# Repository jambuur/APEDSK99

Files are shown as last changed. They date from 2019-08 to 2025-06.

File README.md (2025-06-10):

# APEDSK99 (Arduino Peripheral Expansion for the TI-99/4a)

### *July 2025 Newsflash: WiFi suggestion*
I did get a number of questions regarding a WiFi option using the Arduino WiFi shield. Initial investigation suggested a lack of memory so to make it fit I had to reduce other functionality. This I didn't want to do. However, there is a simple solution. There are devices that accept a wired Ethernet connection and bridges this to a WiFi network of your choice. It works a treat. Check out IOGEAR etc.

### *July 2024 Newsflash: IDEDSR adaption*
I am currently trying to adapt Fred Kaal's version of the DSR for Thierry Nouspikel's IDE card to APEDSK99. Not sure of a successful outcome yet as there are major design and hardware differences to take into account; the first experiments are encouraging though. If it works it will be a valuable addition to APEDSK99 as you would be able to mount and use existing MAME HD images on your TI. It will also save me from the big headache of trying to define APEDSK99 as a new device in MDOS (see below).

### *January 2024 Newsflash: Case 3D design files available*
With the help of an Industrial Design student I have finalised a case for APEDSK99, (loosely) following the style of the Speech Synthesizer. 
On a side note, I have been able to lay my hands on a Myarc Geneve card. As I don't have a PE Box I am building a standalone system including a modified APEDSK99 for booting and floppy / HD emulation. 

### *February 2023 Newsflash: Major Update in progress*

Check the TI Italian User Club for a review of the new version: https://www.ti99iuc.it/web/index.php?pagina=articoli&artid=219#.Y-gqDi9BxaS

Currently working on updating this Github page, Youtube channel etc. Biggest takeaway is that APEDSK99 is now pretty much plug and play. 
I am thinking of either supplying pre-assembled APEDSK99 shields, leaving it to you to source a cheap Arduino UNO + Ethernet Shield combo from Ebay, AliExpress etc.
Alternatively, I could supply complete kits; I have also been approached by a web shop interested in the same. 
Stay tuned :-) 

### *Arduino-based DSKx emulator / 32K / FTP / NTP shield for the TI99/4a*

APEDSK99 is an Arduino shield that emulates 3 DS/SD/80T floppy drives for the TI99/4a home computer. Combined with a Arduino UNO and an Ethernet / SD shield it allows you to load, save and use disk floppy images (DOAD) on a SD card or FTP server. It includes the necessary 32K RAM expansion and adds NTP date and time to BASIC. The APEDSK99 shield plugs directly into the side port and is powered separately from a USB cable. 

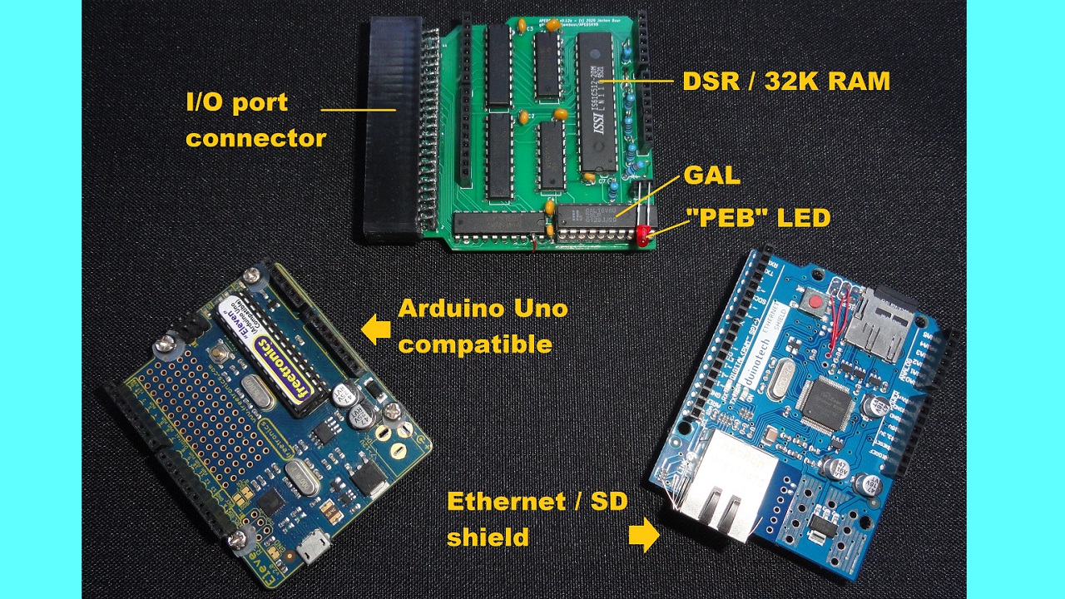
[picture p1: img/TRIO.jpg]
KiCAD 3D view


Like the TI, APEDSK99 is based on good old through-hole technology. The TI<->shield interface is the familiar design, with 74HCT541 buffers for address lines and a bi-directional 74LS245 buffer for the databus.  A 64Kx8 RAM stores the DSR code and provides the 32K RAM expansion. CRU is emulated through memory mapped addresses, simplifying shield design. A user-selectable binary DSR file is loaded into RAM at >4000 by the Arduino at powerup / reset. 

The Arduino UNO controls the TI interface, has R/W access to RAM, can halt the TI and tries to act as a FD1771. As GPIO pins are in rather short supply, Arduino RAM addressing is serial-to-parallel through 74HC595 shift registers. 

A status LED indicates APEDSK99 access as well as showing possible error codes.

The DSR is still very much the original TI Disk Controller ROM, but adapted to interface with a reliable SD card instead of wonky floppies. 
DSR code optimisation made enough RAM available to include some useful BASIC CALL routines. I think it's rather nice that most of the orginal programmers' blood, sweat and tears lives on.

### *How does it work?*

When the TI issues disk controller commands by writing to the various FD1771 registers, the Arduino receives an interrupt on one of its GPO pins. This interrupt is generated by a GAL which monitors A0, A13, A14, A15, WE* and MEMEN* sideport signals. On receiving an interrupt, the Arduino then:

1. halts the TI by making READY low; this simultaneously enables the shift registers
2. disables the sideport interface buffers
3. enables the Arduino RAM control bus
4. executes the command including updating the relevant FD1771 and CRU "registers"
5. executes the opposite of steps 3, 2 and 1

The GAL also does the memory decoding for the 32K memory expansion.

### *DOAD's*

DOAD's are stored in root folders on the SD card or on a FTP server. Default APEDSK99 files include a DISKS folder with a bunch of useful images to get you started. DOAD filenames must follow the DOS 8.3 format and have a ".DSK" extension. At powerup or reset the Arduino looks for optional \_APEDSK1.DSK / \_APEDSK2.DSK / \_APEDSK3.DSK_ files and maps them accordingly so you can have your favourite apps ready to go. The DSR includes all necessary CALL's for DOAD and DSK management.

Once a DOAD is mapped to a particular DSK, it behaves very much like a normal (but rather speedy) floppy. 

Regarding FTP, on my setup (a Linux server with VSFTP within the same LAN segment) I get about ~22Kbyte upload / download speed. In practice it means 6-7 seconds between the TI-BASIC FTP CALL for a SS/SD image and back to the friendly flashing cursor.

### *BASIC support*

The DSR includes some 15 additional BASIC CALL's but there is really only one to remember, **CALL AHLP**:
<p align="center">
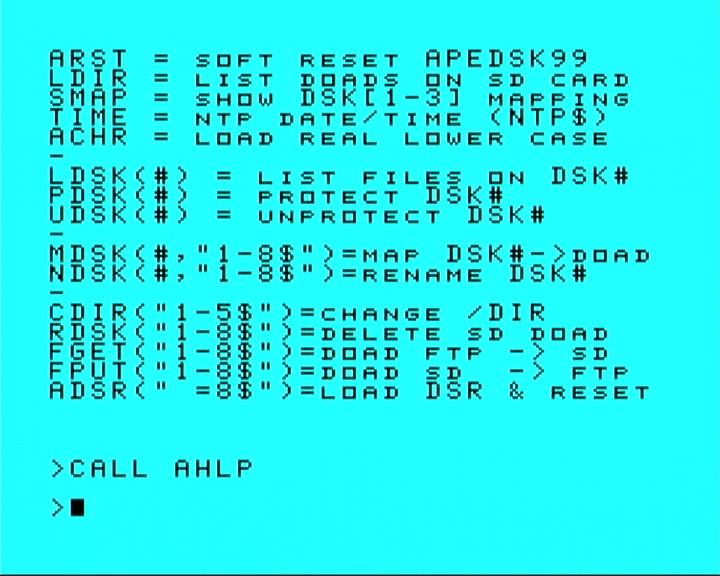
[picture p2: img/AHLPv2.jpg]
  
</p>

**CALL ARST** resets APEDSK99 including reloading the current DSR. It is a handy way to get your DOAD mappings to their default state. It is functionally the same as pressing the Arduino reset button and sort of the same but not really as power cycling. 

**CALL LDIR** list the DOAD's in the current selected directory on the SD card, displaying the DOAD name, TI DISK name and DSK characteristics:
<p align="center">
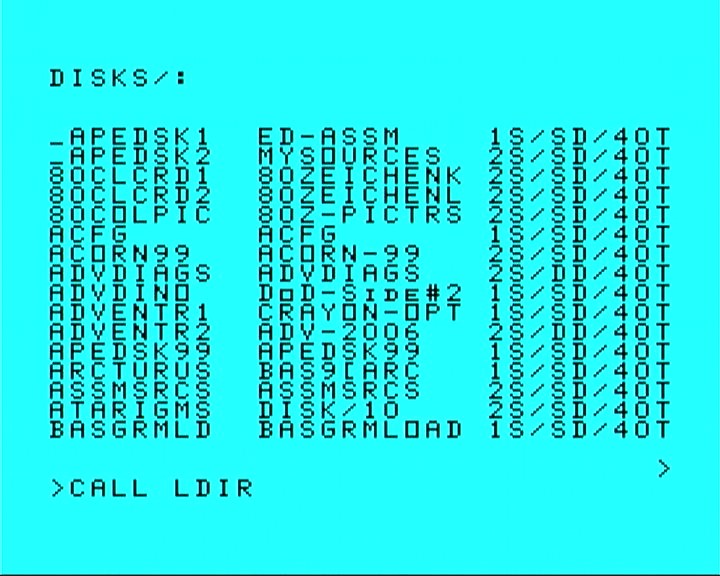
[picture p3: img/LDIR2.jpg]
  
</p>

**CALL SMAP** shows the current DSKx -> DOAD mappings, extended info and the available directories on the SD Card:
<p align="center">
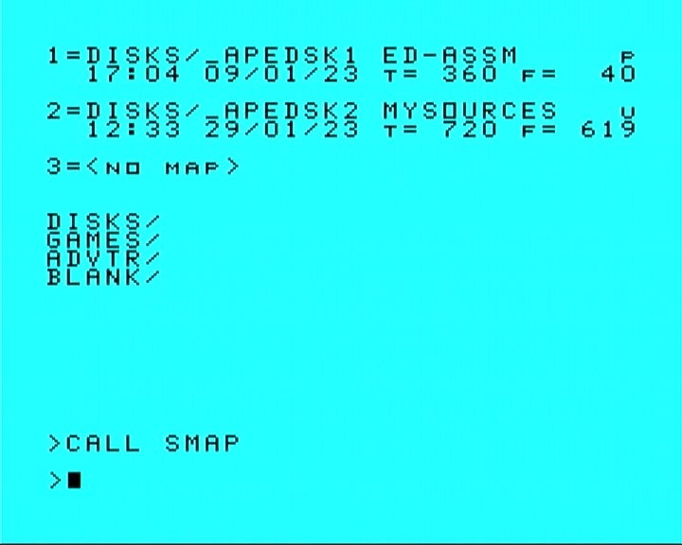
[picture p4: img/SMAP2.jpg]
  
</p>

**CALL TIME** gets the current date and time from an NTP server. If you define a BASIC variable NTP$ of exactly 16 characters before the CALL, the NTP data will be stored for use in your programs:
<p align="center">
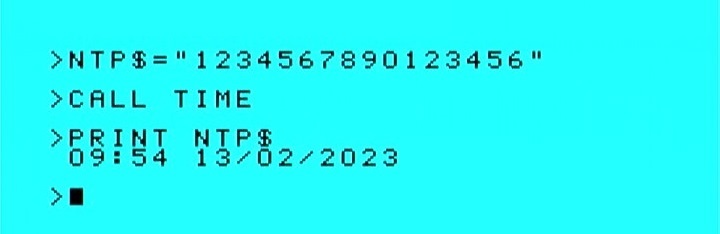
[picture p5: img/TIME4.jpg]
  
</p>
NTP is also used in the background to update a DSK's timestamp when creating/changing files or formatting.
<br/>
<br/>

**CALL ACHR** redefines the "lower capital" character definitions to true lower case. It's a bit of a bummer that BASIC constantly reloads the original definitions in command mode so you can really only enjoy lower case characters while running a BASIC program. What has this feature  to do with DSK's I hear you ask? Well, nothing really but it gives you an example of developing useful CALL's with APEDSK99: 
<p align="center">
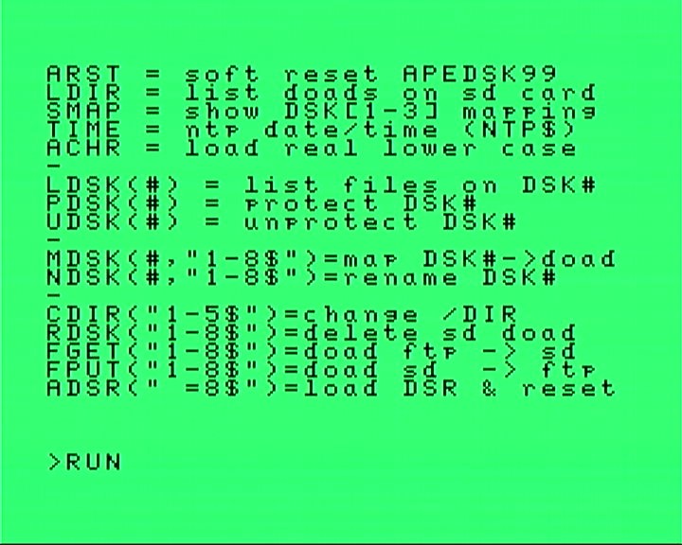
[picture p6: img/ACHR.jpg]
  
</p>

**CALL LDSK** list the files on a DSK; I always thought that was a really nice feature of the C64 so here it is. LDSK uses the last DSK\# that was accessed if you ommit the [1-3] parameter:
<p align="center">
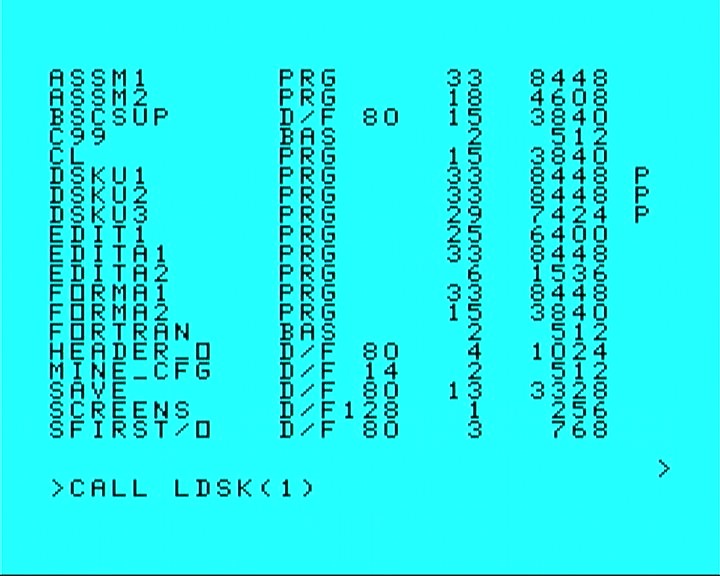
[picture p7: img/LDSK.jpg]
  
</p>

**CALL PDSK** and **CALL UDSK** apply or remove a virtual "sticker tab" (remember those?). With the "tab" applied, APEDSK99 can't write to the DSK. Under the hood the Protected flag at 0x10 in the Volume Information Block is set/reset:
<p align="center">
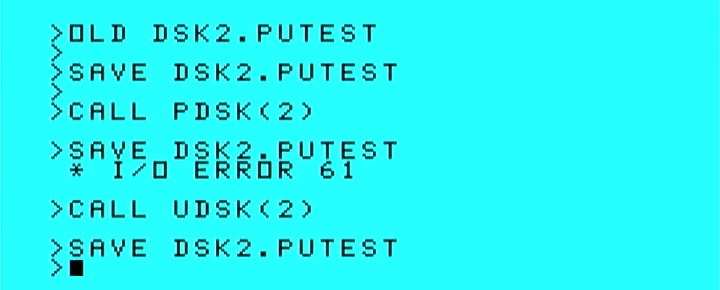
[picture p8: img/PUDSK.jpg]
  
</p>

**CALL MDSK** maps DSK[1-3] to a DOAD. The DOAD file name is the DOS max 8 character part without the extension (see **CALL LDIR** above).  

**CALL NDSK** renames a mapped DOAD. The TI DISK name is set to match the DOAD 8 character name. With renaming the DSK, the current mapping is deleted as the DOAD has now a new name. This command is handy for quickly creating a freshly formatted DSK. Just **FGET** a clean image (I use either FLOPPYSS.DSK or FLOPPYDS.DSK) and rename accordingly.

**CALL CDIR** changes the working directory. The SD Card image contains a /DISKS folder with lots of goodies and a /BLANK directory with the abovementioned clean images. One restriction is that you have to create additional directories on an external system as there is no CALL for that. 

**CALL RDSK** removes a DOAD from the SD card. In line with BOFH standards no confirmation is required but the DSK in question needs to be UNprotected.

**CALL FGET** and **CALL FPUT** load or save a DOAD from your FTP server of choice. Similar to **RDSK**, to overwrite an existing DSK on the SD card it needs to be UNprotected. To prevent overwriting images on your FTP server simply make them read-only.

**CALL ADSR** loads a DSR file from the SD card and resets APEDSK99. If the DSR file doens't exist or is invalid the default file APEDSK99.DSR will be loaded instead. The current DSR filename is stored in EEPROM so will survive resets and powerdowns. After loading a DSR, a soft-reset may be required to execute any DSR powerup routines. 

NB: 
**LDIR** and **LDSK** can generate multiple screens of info. A ">" will show up at the bottom right for you to press either \<SPACE\> for the next screen or \<ENTER\> to go back to the BASIC prompt.

### *APEDSK99 configuration*
Configuring APEDSK99 is easy. All it takes is to run a BASIC program called ACFG from DSK1:
<p align="center">
  
</p>

The program has to run from TI BASIC (why? see _What about Extended BASIC_ below):
<p align="center">
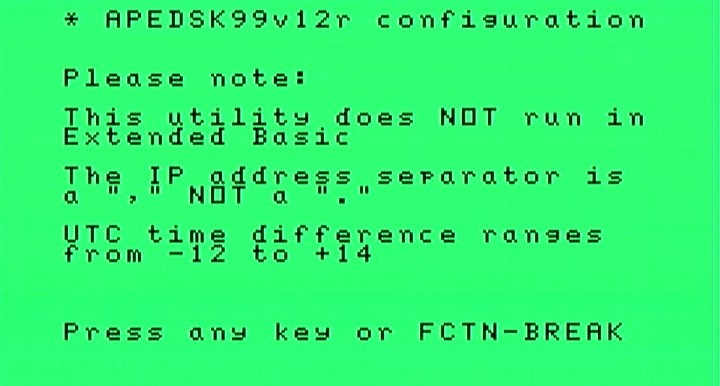
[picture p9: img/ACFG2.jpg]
  
</p>
  
The programs shows the current configuration before asking for updates. 

The new configuration is then applied to APEDSK99. If NTP is successfully configured the program shows the local date and time. The configuration is saved in EEPROM and used with every reset / powerup:
<p align="center">
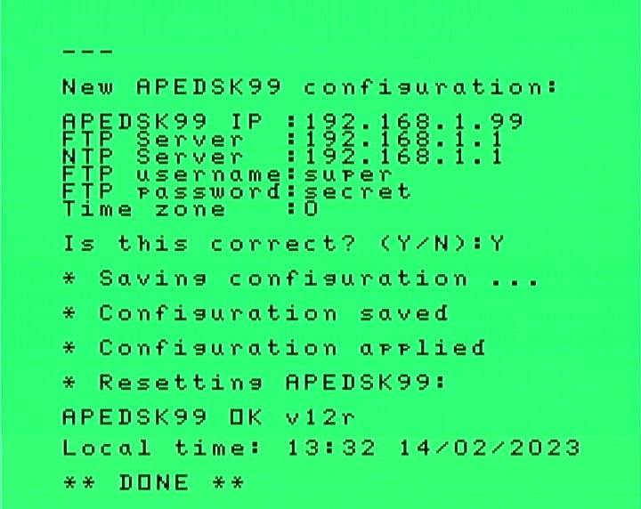
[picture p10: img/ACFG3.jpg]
  
</p>

### *What about Extended BASIC*
Yes, good question as I take it EXBAS is used over TI BASIC by the majority TI enthusiasts. Obviously I wanted to support vanilla console users (like the ones re-entering the hobby after xx years such as myself). But that doesn't explain why EXBAS couldn't be used to run the configuration program. Well, the problem is that EXBAS doesn't support external CALL's in programs, only from the command line. This would mean you have to type in a set of commands instead of a more or less automated setup. Not a good idea I thought.

**UPDATE 16/1/2024**: I now have provided EXBAS support through CALL LINK as an alternative to execute DSR CALL code, for example CALL LINK("MDSK",1,"ACFG"). Adapting the configuration program to EXBAS is left as an exercise to the reader.

### *Ignition sequence*

The DSR containes a powerup routine (the original TI DISK Controller routine if fact) that needs to be executed before you can properly use DSK's.
So switch on the TI first, apply power to APEDSK99, wait a second for APEDSK99 to load the DSR (short flash from the LED) and then soft-reset the TI with \<FCTN\>-\>QUIT\> to execute the DSR powerup routine.

### *Error codes*

The LED can flash in the following intricate error patterns:

1. *flash*            : SPI / SD Card fault/not ready
2. *flash-flash*      : can't read DSR binary image (/xxxxxxxx.DSR)
3. *flash-flash-flash*: no valid DSR header (>AA) at DSR RAM >4000

### *Uploading Sketches*

You should make sure APEDSK99 is idle or even better, switch off the TI before uploading the APEDSK99 sketch from the Arduino IDE. If you don't, there is a slight chance the Arduino bootloader gets corrupted and you'll need a second Arduino to restore it. Yes I have been there.  

Alternatively you could connect [_Analog 1_ to _+5V_](img/A15V.jpg) with a jumper wire before uploading; this disables the APEDSK99 sideport buffer IC's so you can leave the TI powered on. In fact, if you intend to put APEDSK99 in some sort of case, plan a switch for this. It's not only handy for uploading sketches but also for temporarily circumventing _TI Extended BASIC_'s LOAD feature.

### *Updating the DSR*

I compile the DSR .a99 file with [xtd99 TI99 cross development tools](https://endlos99.github.io/xdt99/) and then use [this hex editor](https://mh-nexus.de/en/hxd/) for padding the binary file with zero's to the full 8KB. After that it's just a matter of saving the binary file as APEDSK99.DSR in the root of the SD.

### Feeling Brave - DIY from scratch

If you decide to build one yourself, I have compiled a handy document to get you started. Just ping me with any questions through Github, YouTube or AtariAge (JJB).

### A suitable case

I have teamed up with an Industrial Design student from a local university and have come up with the design below. It (very) roughly follows the design of the Speech Synthesizer and has a handy hatch to access the SD card and reset button:

<p align="center">
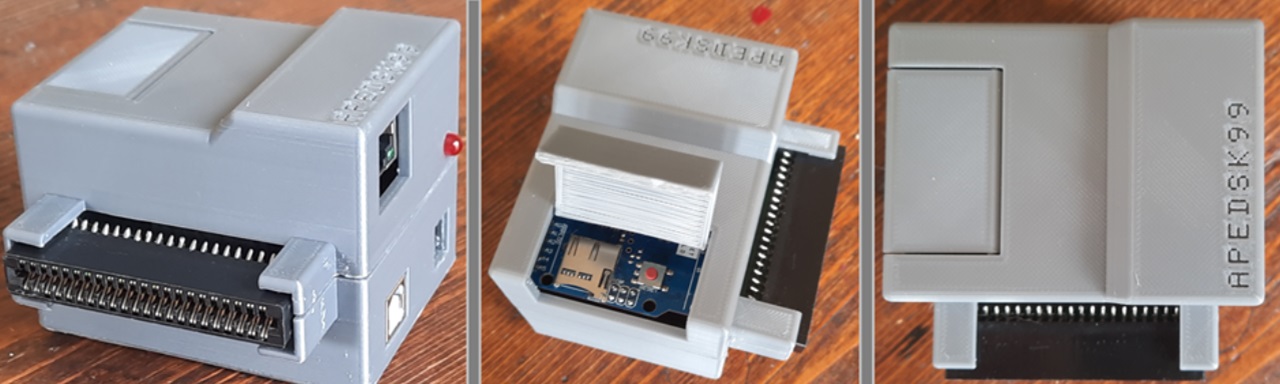
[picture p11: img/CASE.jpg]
  
</p>

### *I know*

Writing software is a hobby, not my profession. No doubt some gurus would achieve the same functionality with half the code. But I dare to say that at least the basic DSR I/O routines in the sketch are reasonably efficient, useful and fast. Anyway I am content with dusting off that stack of virtual floppies, have a beer and admire my work. 

Feel free to improve and share!

### *Bugs*

If a particular program or module behaves nicely by accessing disks solely through the regular DSR routines there shouldn't be any new ones (are there any existing disk controller bugs?) In other words, any funky index hole math or weird copy protection schemes will likely fail. 

Not so much a bug but an annoyance is that the FAT format (as used on the SD Card) doesn't support any sorting whatsover; so if you have been actively **FGET**'ing images from your FTP server you might find the **SDIR** list slightly out of alphabetical order. There are a number of "FAT Sorter" programs for different OS's that can restore the order for you (the one I use is included in the repository).

And yes, if I had thought it through a bit more I would have designed APEDSK99 with the USB and Ethernet connectors facing backwards. Anyway what's done is done and unless there is a push for a major revision (unlikely) you'll (we) have to live with this minor inconvenience.

### *Future*

After (of course) I came up with the name APEDSK99 I realised that DSK emulation is just a first application. The APEDSK99 shield is actually a generic interrupt-driven DSR interface to a substantial catalogue of available Arduino shields. Also, the Arduino has full access to the 32K RAM expansion and since it uses a 64Kx8 RAM chip there is an additional 24K available for additional DSR, program code or device data sharing.

### *Acknowledgements*

This project owes a lot to Thierry Nouspikel's marvelous [TI Tech Pages website](http://www.unige.ch/medecine/nouspikel/ti99/disks.htm) which has a wealth of information on the TI Disk Controller, including a commented disassembly of its DSR ROM.

Another great source of information has been Monty Schmidt's excellent book [Technical Drive](img/MSTDrive.jpg). Monty went on to do great things, check out [SoundForge](https://www.magix.com/us/music/sound-forge/). Monty has now made his book publically availabe: https://github.com/wuntusk/technical-drive

The Arduino's serial-to-parallel RAM addressing scheme is neither new or mine but I have gratefully used part of [this excellent project](https://github.com/mkeller0815/MEEPROMMER) by Mario Keller.

Last but not least I virtually stumbled across my old friend Frederik "Fred" Kaal who I hadn't seen for 30 years after moving to the other side of the globe. Long live the Web and places such as AtariAge. Fred was a TI wizzard back then and [still very much is](http://ti99-geek.nl). His expert input has been of great help.

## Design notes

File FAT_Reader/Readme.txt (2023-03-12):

---------------------------------------------------------------------------
  FAT Reader v0.8 rev.1                             written by: A. Sanasi
---------------------------------------------------------------------------

Introduction
------------

Ever since MS-DOS based Windows98 was discontinued, I longed for a way
to physically sort directory entries to my liking (I still make extensive
use of the Command Prompt and hate it when things are not orderd as I
want).  Before that I had used the fabulous LFNSORT command-line tool by
D.J. Murdoch, which alas does not work on NT-based operating systems.

Even after many years, still no program seems to be able to do this job
right.  Some programs only check drives connected to the USB port, allow
only alphabetical sorting with no manual sort options, sort only music
files, or even require Windows Media Player to be present.  But what if
you want to sort other things too?  Like image files on a digital frame
or video files on your local harddisk?  Or if you simply prefer a
non-alphabetical order with directories and files in a special
arrangement?

Other programs just work with tricks by simply moving all files into a
temporary directory and then move them back in the desired order.  The
problem with this approach is, when you have for example 50 file entries
that you move out of a directory and then back, you don't get 50 sorted
file entries, you get 50 (invisible) deleted entries followed by 50 normal
file entries, because Windows will always try to append first when creating
new entries, not overwrite.  Even worse, when the cluster of a directory
can hold let's say 128 entries and you move 100 files out and back in,
Windows will first use up the remaining 28 free entries and then start
overwriting the entries marked as deleted (because that's more efficient
than allocating a new cluster to expand the directory), resulting in file
entries 29 - 100 being on top, followed by 28 remaining deleted entries,
followed by file entries 1 - 28.

The only program and my personal favorite that really gave you full sorting
control was YAFS (Yet Another FAT Sorter) by Luis Henrique Oliveira Rios.
Alas, this one has no GUI and works with .XML lists that you can only
handle with an appropriate editor, and you have to set the new order by
manually changing numbers individually for each file, which is VERY
tedious.  It also seems to not keep deleted entries, so you can't undelete
anything after the sorting anymore in case you need to.

Luckily, recently a friend explained the basics of VB .NET to me through
Skype (all I knew before was a little bit of x86 assembler), and with that
knowledge I was finally able to write my own program.  Aaand here it is! ;)
This one not only has a GUI, but can also do real sorting on the filesystem
level.  And since it communicates with the device drivers, it should be
able to handle all drives that Windows recognizes as FAT, be it MP3 player,
USB stick or harddisk, even mounted TrueCrypt volumes work.

Disclaimer
----------

This really is my VERY FIRST program in a high-level language (everything
not being assembler counts as high-level for me).  All the programming
magic I was able to learn on the internet went into it, and I tried my
best to make everything as fool-proof as possible.  But I don't know much
about Windows interna, so if you purposely try tricking the program to
write data to a device it shouldn't, there is a chance you might succeed.
JUST DON'T DO IT!

I'm not a programmer, only a hobbyist at best.  Why?  For the same
reason why I'm not a brain surgeon.  If you don't do it solely for fun
(for example if you liked the ending of "Silence Of The Lambs" part 2
so much), then you have to know the solution right away and can't search
hours online for every little problem.  And I had to do a LOT of
searching.

Real programmers (those who don't eat quiche) would probably scream in
agony if they saw my source code, and some of my solutions might not be
very professional.  The program wasn't planned this way from the start,
I just kept adding and changing stuff while it progressed.  But hey, it
does seem to work... sort of.

Usage is solely at your own risk, I guarantee for nothing and won't be
liable for anything.

Now let's get started.

Get Drives
----------

This program can only handle drives that use the FAT filesystem format
(FAT12, FAT16 and FAT32 are supported).  Click on the button "Get Drives"
to identify all FAT devices on your system, then select the device you
want to modify from the listbox below.

Open / Close
------------

To physically sort directory entries, exclusive read and write access
is needed.  Click on the button "Open" to open the selected drive for
exclusive access.  Make sure that all files on that drive are closed and
that you have the appropriate access rights (right-click on the program
and choose "Run As Administrator" if you get a warning).  Also, if you
are using a command-line window, make sure that you are not currently
located anywhere on that particular drive.

After all changes have been made and written, you can click on "Close"
to allow other applications access again or if you want to select a
different drive.

Directory Sorting
-----------------

The contents of the selected directory are shown in the list on the right,
with the name of each entry in the left half and the type of the entry in
the right half, easily distinguishable by different colors (hidden entries
are shown slightly darker than normal entries).

As of v0.8 rev.1, the program will remember the new column widths if you
modify them.  To resize, hover with the mouse above the right border of the
header field of the column that you wish to resize (so that it displays a
double-sided arrow), and then drag the column border.  You can now also
resize the program window, and the columns will automatically adapt in a
matching ratio.

To automatically sort a directory, simply click on the header field of the
list, and it will cycle between ASCending sort (0 - 9, A - Z), DESCending
sort (Z - A, 9 - 0) and no sort (the original directory order).  You can
also influence sort behavior under "Main Menu" - "Settings" - "Sorting
Options" (see below).

To manually sort a directory, left-click on any entry and drag it to the
desired new position while keeping the mouse button pressed.  If you reach
the top or bottom of the list it will start scrolling, so you can easily
reach positions further up and down without having to use the scrollbar.

Changing Directories
--------------------

The path of the current directory is shown in the white textbox right
below the buttons.  To switch to a directory further down in the tree,
double-click on its entry in the directory list.  To switch to a
higher-level directory in the tree, double-click on the ".." entry
in the directory list.  The "." entry represents the current directory
and will just re-load that when clicked.

Manual Directory Sorting By Keyboard
------------------------------------

You can also sort directories manually by using the keyboard.  While
the directory list has focus, press <Enter> once to show the selection
bar.  Press <Enter> a second time to 'grab' a selected entry and another
time to release it again.  A white focus rectangle will appear around
the entry while it is moveable.

Use the <Up> and <Down> keys to move the selection, <PageUp> and <PageDown>
keys to move it page-wise, and <Home> and <End> keys to jump to the begin
and end of the list.

To switch directories, select the appropriate entry and then press
<Enter> two times in quick succession (like a mouse double-click).

Pressing the <Left> or <Right> key will sort the directory automatically
(same as clicking on the list header field).

Please note that the keyboard control was a last-minute quick-and-dirty
addition (kept separate from mouse control and in a way so I could
completely remove it from the source code again within one minute) and
thus follows more my personal liking than Windows standards.  Originally
I wanted to simply block all keyboard input for the directory list
altogether, until I noticed that with larger directories, manual sorting
by keyboard could be much faster than with using the mouse.

Add To Queue / Update Queue / Remove From Queue
-----------------------------------------------

This program works with a Queue list, which means that no data whatsoever
will be written until you explicitely request processing of this list
(this is an intended security measure).  When you have sorted a directory
to your liking, click on "Add To Queue" and it will be added to the list.
From now on, this directory will be shown to you as it is stored in the
Queue and not as it is stored on the disk, giving you a preview of how
things will look after applying the changes.

The Status field on the left shows you the state of the current directory.
"Not Stored" (red) means the directory isn't in the Queue at all,
"Stored / Up-To-Date" (green) means the directory is stored in the Queue
and matches the displayed directory list, "Stored / Changed" (yellow)
means the directory is stored in the Queue, but the displayed directory
list does not match anymore (because you made further changes).  In the
latter case, the "Add To Queue" button changes to "Update Queue", and
when you click on it, those new changes will be added too.

If you decide that an added directory should not be processed at all, you
can click "Remove From Queue" to remove it from the list.

Write Data To Drive
-------------------

If you are satisfied with how everything looks, click on "Write Data To
Drive" to do the actual writing.  The program will then process all
directories that are stored in the Queue and write them to the disk in
their new order and with whatever modifications you specified.  This is
the ONLY time where actual changes are made to the disk.

Disk writing must be explicitely activated first (see "Main Menu" -
"Settings" - "Activate Disk Write").  If the program acted weird in
some way during your modifications or if things don't look as intended,
DO NOT WRITE ANYTHING.

The Main Menu
-------------

The main menu offers additional options and features for sorting and
error checking.

Main Menu - Settings
--------------------

If you 'just want to sort', then you can (and should) stay with the
"Simple Mode", in which case deleted entries and long filenames will
not be touched.  If you want to have more functionality and/or sort
more than one directory at a time, then turn on "Professional Mode".

Checkboxes
----------

In "Professional Mode", some checkbox options are shown on the left that
offer extra modifications beside simple sorting.  When a directory is added
to the Queue, those options are stored with it, and are shown accordingly.

"Deleted Entries" refers to directory entries that are marked as deleted
(first byte = E5), which can be both entries of files/folders or long
filename parts.  If for example a file has a long filename that takes up
three entries in the directory, after deletion this would count as four
deleted entries (one for the file as such and three for the long filename
parts).

If a directory contains deleted entries, the program shows you its number
and if they are all located at the end of the directory (after all the
visible entries), or if the deleted entries and the visible entries are
mixed (at least one deleted entry is located before a visible entry).  You
can choose to either remove them completely (overwrite them with zeroes)
by checking the option "Remove Entries" or to keep them by checking
"Move Entries To End", in which case they will all be placed after the
sorted visible entries.  The way my program works, you cannot keep the
deleted entries mixed with the visible entries, so if you try un-checking
both checkboxes, the selection will always default to "Move Entries To End".
Also, if all deleted entries already are located after all the visible
entries, that selection is grayed out.

"8.3 LFN" refers to names where their ANSI shortname matches their Unicode
Longname counterpart (apart from upper / lowercase).  Technically, those
LFN are not really needed, but they do consume directory space, so checking
the option "Remove 8.3 LFN" will remove those special longnames.  The list
on the right will display all name fields accordingly.

"Real LFN" refers to names where their Unicode Longname is different from
their ANSI shortname.  Removing those LFN can result in programs being
unable to find their paths and files anymore (because with the LFNs gone,
paths and names will be different).  Removing those LFN is therefore NOT
ADVISED, but you can check the option "Remove Real LFN" if for whatever
reason you want to do it.  The list on the right will display all name
fields accordingly.

Main Menu - Settings - Sorting Options
--------------------------------------

Here you can refine the behavior of the automatic directory sort (when
you click on the header field of the list).  If for example you want
folder entries to always be on top or want to sort only file entries,
then change the options appropriately and the automatic sort will take it
into account (changes take effect after you do the next automatic sort).

Main Menu - Settings - Activate Disk Write
------------------------------------------

Disk writing must be explicitely activated (this is an intended security
measure, originally added for risk-free testing), otherwise writing will
only be simulated.  A simulated write does everything EXACTLY as a real
write, it sets the file pointer, creates the new sector data, writes info
to the logfile etc., with the sole exception that the function which does
the actual writing is never called.  Activate this option only if you
really mean it (and say GOODBYE to your data, WUA HA HAA... ahem).

Main Menu - File
----------------

The options under "File" incorporate a cool feature that I always liked
in D.J. Murdoch's LFNSORT: it lets you create a directory sorting list
in plain text that you can then modify in a text editor.  "Load Queue
List" reads an existing list, while "Save Queue List" saves whatever is
currently stored in the Queue to a text file.

In "Professional Mode", you have two additional options named "Include
Checkbox Selections" and "Process Checkbox Commands".  If "Professional
Mode" is active and you activate "Include Checkbox Selections" before
saving, then those selections will also be saved to the list as additional
commands, individually for each directory.  Likewise, if "Professional Mode"
is active and you activate "Process Checkbox Commands" before loading,
addidional commands in the list will be processed.  Otherwise they will be
ignored for security reasons, which means that deleted entries will always
be kept and no long filenames will be removed.

If a directory is already stored in the Queue, any reference to it in a
list that you load will be ignored (manually-made additions to the Queue
always have priority).  If you want to make sure that every directory is
processed, choose "Main Menu" - "Clear" - "Empty Queue" first.

When you load or save a list, remember to choose the right format.  The
UTF-8 option will create a directory sorting list with longnames where
they are available and shortnames where longnames are not available, based
on the UTF-8 standard (chars 32 - 127 as single-bytes based on the
ASCII-standard, other chars based on Unicode).  ANSI will create a
directory sorting list with shortnames only, based on the currently
active ANSI codepage.

Do not load a list that was saved in UTF-8 format as an ANSI list or
vice versa, because then many characters might be read incorrectly and
matching / sorting will be incorrect.  Of course, since all entries
that are not found are only put at the end of the directory and thus
won't get lost, the worst that can happen is that the entries in the
sorted directories are not in the desired order afterward or that a
directory isn't sorted at all because its path wasn't found.

If you want to be on the safe side, I suggest always choosing UTF-8 as
your preferred format.

Also, please note that when sorting directories based on a text file,
the program has to do a string compare for every given entry with all the
entries in the directory that is sorted until a match is found, which can
be a bit time consuming depending on the total number of directories.

The Queue List File Format
--------------------------

If you are unsure about how a working Queue list should look like, let it
create by the program and only make modifications.  The basics are as
follows:

A valid directory always starts with a full pathline to the directory that
will be sorted, followed by the directory entries in the desired order.
Entries that are not listed or not found in the specified directory will
be added to the end after all the sorted entries.  So for example, if you
only want one specific entry to be on top of a directory, it's enough to
specify the path followed by the name of that one entry.

Checkbox Commands must start with an asterisk (*) and can be placed
anywhere within a valid directory.  Valid commands are

To remove deleted entries in that directory:

    * Rem Deleted

To remove 8.3 shortnames in that directory:

    * Rem 8.3 LFN

To remove Real LFN in that directory:

    * Rem Real LFN

Checkbox Commands must be present for each directory individually,
otherwise the program defaults to keeping all deleted entries and not
removing any long filenames in that directory.  Also, if the specified
directory does not contain any deleted entries or matching LFN entries,
the commands are ignored.

Main Menu - Recurse
-------------------

In "Professional Mode", you can also add or remove subdirectories
recursively instead of sorting and adding each one manually.

"Add Recursive" lets you add all subdirectories of the current directory.
In the new window that appears, select the options that you want to be
applied (default always is the current sort and checkbox selections) and
then click on "Start".  All subdirectories will be added to the Queue,
modified based on the options you chose.

"Remove Recursive" removes all subdirectories of the current directory
from the Queue.  This is for example useful if you added subdirectories
and then want one subdirectory and everything below it excluded.  First
go to that directory and select "Remove Recursive" to remove all
subdirectories, then click on "Remove From Queue" to remove the
current directory.

Main Menu - Clear
-----------------

"Empty Queue" removes all entries from the Queue.  Choose this option if
you want to get rid of all the modifications made so far.

Main Menu - Debug
-----------------

This program offers extensive debugging information.  Originally all this
was sent to a textbox, so I could see what the program does and better
check for errors (which was REALLY needed).  When everything ran halfway
stable, I decided to not remove the functions but instead re-direct the
output to a logfile.  So if you think something is not working as it
should, or if you just want to get a deeper insight about how things
are done, this is where you should start.

"Begin Logging" and "End Logging" starts and stops logging.  The output is
saved to a file named "LogFile.txt" located in the same directory as the
program.  While logging is active, a small label will flash at the top
right of the program window to indicate this.

By default, only basic info like positioning of the file pointer and sector
read / write messages are logged.

"Extra Logging Options" lets you select additional stuff that you want to
be logged.

"Log Drive Info" will write detailled info about the available drives to
the logfile (whenever you click on the button "Get Drives").  Activate
this if you want to see if your drives are recognized correctly.

"Log Sectors Read" will write the data of every sector that the program
reads to the logfile, in both hexadecimal and ASCII representation
(similar to a Hex Editor output).  Activate this if you want to check
if the program interprets all data correctly.

"Log Sectors To Write" will write the data of every sector that the
program is going to write to the disk to the logfile, in both hexadecimal
and ASCII representation (similar to a Hex Editor output).  Activate this
if you want to validate the data that will be written.

"Log Queue List Loading" will write detailled processing info to the
logfile when you load a Queue list text file.  Activate this if you want
to check if a Queue list is processed as intended.

Be careful which logging options you activate and for how long, or the
logfile will soon get pretty big (for example, you really shouldn't
select "Add Subdirectories" from the root of your full 1 TB harddisk
when logging is active).

For The Professionals
---------------------

If you feel safe enough, you can use some command-line options to
bypass certain security measures.

To start with Professional Mode active

   -Professional         or      -Pro

To start with checkbox default "Remove Deleted Entries"
(change only has effect when Professional Mode is active)

   -Remove_Deleted       or      -Rem_Del

To start with checkbox default "Remove 8.3 LFN"
(change only has effect when Professional Mode is active)

   -Remove_8.3           or      -Rem_8.3

To start with deactivated warning message for Real LFN removal

   -No_LFN_Warning       or      -No_Warn

To start with checkbox default "Remove Real LFN"
(change only has effect when Professional Mode is active - this
will also deactivate the warning message for Real LFN removal)

   -Remove_Real          or      -Rem_Real

To start with activated disk writing

   -Activate_Write       or      -Write_On

To start with activated "Process Checkbox Commands" and "Include
Checkbox Selections" for Queue List Loading

   -Process_Checkboxes   or      -Use_CB

Example:

   FAT_Reader.exe -Pro -Activate_Write

will start the program in Professional Mode and with disk writing enabled.

Freqently Asked Questions
-------------------------

Q:  How can I sort a whole drive?
A:  Go to the root directory of the drive.  Then first select "Main Menu" -
    "Settings" - "Professional Mode" and then "Main Menu" - "Recurse" -
    "Add Subdirectories".  Click 'Start' to add all subdirectories to the
    Queue based on the selected sorting options.  Then sort the root
    directory accordingly and click "Add To Queue" to add that one too.

Q:  Checkbox selections seem to change without reason.
A:  When a directory is displayed that is already stored in the Queue, the
    checkboxes will reflect the selections stored with that directory.  If
    a directory is not in the Queue, the checkboxes will display their
    current default settings.  Whenever the user manually changes a
    checkbox, this selection becomes the new default.

Q:  Can't uncheck "Move Entries To End" checkbox.
A:  When the program reads the entries of a directory, it creates two
    separate lists.  One contains all the normal entries, while the other
    contains all the deleted entries.  That's why "Move Entries To End"
    must be used if you don't want the entries to be deleted, and the
    checkbox reflects that.  But it wouldn't make much sense anyway to
    keep deleted entries mixed with sorted entries, now would it?

Q:  Can't move / sort the "." and ".." directory entries.
A:  Those entries must always be first in any subdirectory, that's why
    they are treated as not movable / not sortable.

Q:  How can I just separate all directory and file entries without
    changing anything else?
A:  Go to "Main Menu" - "Settings" - "Sorting Options" and there select
    "Directory Entries On Top" and also "Don't Sort Directory Entries"
    and "Don't Sort File Entries".  Then the next time you do an automatic
    sort, the program will only split directory and file entries up without
    doing any actual sorting.  It doesn't matter if you choose ASCending or
    DESCending sort in that case, because with this setting, both methods
    will give the same result.

Q:  Options "Don't Sort Directory Entries" / "Don't Sort File Entries"
    are grayed out.
A:  If "Directory & File Entries Mixed" option is selected, you can't
    exclude entries from sorting (such a sort wouldn't make sense).

Q:  Selection disappears when mouse button is released.
A:  That's intended.  Originally I only used mouse control, where it
    doesn't make much sense to keep the last selection visible (in
    contrary to keyboard control, which I added much later).

Q:  Program doesn't write sector data to the logfile when reading from
    File Allocation Table.
A:  The File Allocation Table contains only cluster references (in
    contrary to directory entries, which are much easier to interpret
    with the bare eye).  That's why I purposely left that out.

Q:  Button "Write Data To Drive" is grayed out.
A:  It's not enough to just make changes to a directory, you must also add
    it to the Queue list for processing.  Otherwise there will be nothing
    to write.

Q:  Writing to disk does not seem to have any effect.
A:  You must explicitely activate disk writing first (see "Main Menu" -
    "Settings" - "Activate Disk Write").

Q:  Some error messages are partially not in English / use the system
    language instead.
A:  For certain errors I used the Win32Exception Class to get a detailled
    error message (instead of just showing the returned error code).
    Since those messages are generated by the system, of course they
    are localized.

Q:  Who is General Failure and why is he reading my C:\ drive?
A:  Please see "Disclaimer" further up in this file.  Also check
    out the "Bugfixes" in the "History" section further down.

Q:  You are German, why is this program in English?
A:  I wanted my program to be accessible by as many people as possible,
    so it had to be in English.  Also, it turned out that German text
    doesn't fit as well inside the labels, menus and button fields as
    English text does.

Some Technical Details
----------------------

To get exclusive disk access and to communicate with the drive, Kernel32
API calls are used (CreateFile, LockFile, SetFilePointer, ReadFile,
WriteFile, UnlockFile and CloseFile).  There already were a few examples
for this on the Internet, but only for VB6, so it took me quite a while
to make this work right.  If you want to try too, http://www.pinvoke.net/
is a good place to get info.

If you remove and re-insert a locked USB device, the program will usually
no longer be able to access it, because the assigned device handle will
become invalid.  If you use a fixed card-reader and only remove and
re-insert the card, then access might still work, but the safest option
always is to simply leave the device connected all the time.

The FAT format is determined by using the methods described here:

  http://homepage.ntlworld.com/jonathan.deboynepollard/FGA/determining-fat-widths.html

Info about the File Allocation Table / directory structure etc. mostly
came from here:

  https://www.pjrc.com/tech/8051/ide/fat32.html

Data is read sector by sector, because it started as a 'proof of concept'
project.  Reading whole clusters might be more efficient, but on today's
hardware, I guess speedy code isn't such an issue anymore.

This program does not mess with the File Allocation Table.  If after
removing deleted entries a directory cluster is not needed anymore, the
cluster will remain allocated, just with all zeroes in it.

The displayed directory list is simply a DataGridView (set to adopt the
appearance of a ListView) to which I attach my list of directory entries
as BindingSource and have the fields colored accordingly.  Sounds easy?
It was NOT! ;)

The other FAT Sorter programs that I mentioned at the beginning of this
file can be found here:

   http://www.murraymoffatt.com/software-problem-0010.html

History
-------

v0.1   Proof of concept.  Get drive info, open / close drive, read first
       sector of root directory and follow-up sectors / clusters of a
       pre-set drive to textbox in HEX and ASCII.

v0.2   Display directory entries of a pre-set drive in double-buffered
       ListView with colored fields, change directories by double-clicking
       an entry, basic sorting of entries with mouse.  Functions split
       over several TabControl pages.

v0.3   Selectable drives from ComboBox, display of directory path, more
       sophisticated sort with mouse, automatic sort by header click,
       CheckBox options for deleted entries & LFN, usage of Queue list.
       Dropped ListView altogether in favor of GridView due to badly
       controllable scrolling in certain situations and other
       disadvantages.

v0.4   Menustrip, options to sort directories recursively and to clear
       Queue, basic code for loading / saving UTF-8 / ANSI with dialog.
       Debug data now redirected to logfile, 'About' window added.

v0.5   Queue list loading / saving, automatic scrolling of directory
       list, logging indicator, extra logging options.

v0.6   TabControl removed and all important stuff put on a single form,
       code and design improvements, simple and professional mode,
       bugfixes, command line options, secret functions.

v0.7   Read/Write error warnings and own icons, simple protection against
       noobs with a Hex Editor, extended sorting options, sorting of
       directory entries with keyboard, speed improvements, final testing
       and bugfixing, code cleanup.  Beta Release Candidate #1 ...

       0.7.458.1

       Bugfix: when "Main Menu" - "Debug" - "Extra Logging Options" -
       "Log Queue List Loading" was activated, it was always writing
       this info to the logfile, even when logging was not active.

       0.8.458.2

       Bugfix: program caused an Overflow Exception on 64bit Windows
       systems when calculating a File Pointer Position where the
       low DWORD was bigger than 0x7fffffff (I used a signed 32-bit
       integer instead of an unsigned 32-bit integer for the result).

       From now on also writes Operating System name / version to the
       logfile, to make things more transparent.

       0.7.458.3

       Bugfix: program still caused an Overflow Exception on certain
       systems.  Now I use BitConverter to create the two DWORD values
       for the File Pointer, which finally seems to work as it should...

       0.7.458.4

       Bugfix: program failed to read follow-up clusters of root directory
       on FAT32 formatted devices.  If root directory occupied more than
       one cluster, contained at least one deleted entry in the first
       cluster and was sorted with option "Remove Deleted Entries",
       entries in follow-up clusters and associated subdirectories were
       not accessible anymore.  Because seeing only the first directory
       cluster, with that setting the deleted entries were put at its end
       and overwritten with zeroes, indicating an 'end of directory' at
       that position.

       To fix such damage, the easiest way would be go to that root
       directory and start creating new folders until all the now
       zeroed-out directory entries have been filled with valid entries
       again.  Since the original cluster chain has not been changed, as
       soon as all entries in the first cluster are filled, the entries
       in the follow-up clusters should become accessible again.

       I suggest using the Command Prompt for this & creating new directory
       entries consisting only of numbers (to avoid the creation of long
       filenames that span multiple entries).

       If sorting was done without "Remove Deleted Entries" or no
       deleted entries were present in the first cluster, worst that
       happened was that entries in follow-up clusters remained
       unsorted.

       Beta Release Candidate #2 ...

v0.8   0.8.465.0

       Bugfix: on partitions larger than 2147483647 (7FFF FFFF hex) sectors,
       WriteFile reports success, but 0 byte are actually written.  After
       a REALLY long time of searching and experimenting, I came to the
       conclusion that this may actually NOT be a bug in my program but in
       the Windows File System Driver that handles FAT partitions.  My guess
       is that somewhere the driver may treat the total number of sectors
       as a signed integer instead of unsigned, thus performing negative
       boundary checks, which let all writes fail because out-of-partition
       writes are prohibited...

       My solution: sending FSCTL_ALLOW_EXTENDED_DASD_IO to DeviceIoControl
       signals the File System Driver not to perform any I/O boundary checks,
       and let the Device Driver do it instead.  But then again, who would
       want to sort stuff on a > 1 TB FAT drive anyway, except meeee? ;)

       Also changed Queue List loading to check for a possible UTF-8 BOM
       (Byte Order Mark - EF BB BF) at beginning of file, and a few other
       minor internal modifications.

       Finally willing to not call it a 'beta release' anymore, Woo-Hoo!!

v0.8   0.8.510.1 (rev.1)

       Whelp, as it seems I somewhat broke the scrolling in my previous
       release by setting a wrong GridView height (for automatic downward
       scrolling with mouse to work correctly, the GridView must show
       'complete' rows only).  Now the height is adapted automatically,
       so it should never happen again.

       While at it, finally I also added the option to resize the window
       (previously blocked for the same reason as described above) and
       turned off GridView double-buffering (wasn't really needed anyway)
       to make the resizing bar for the columns show up correctly.  And I
       activated automatic form scaling based on screen DPI setting (for
       those weirdos who get a boner whenever they see a high-resolution
       monitor - it should now scale correctly at 125%, 150% and even 200%).
       Due to my bad eyes, I still use a resolution of only 800x600 and
       simply can't understand all this 'HD craziness'.

Like Misty from "Pokemon", I don't really like bugs.  So if you find
any in my program, please do let me know.

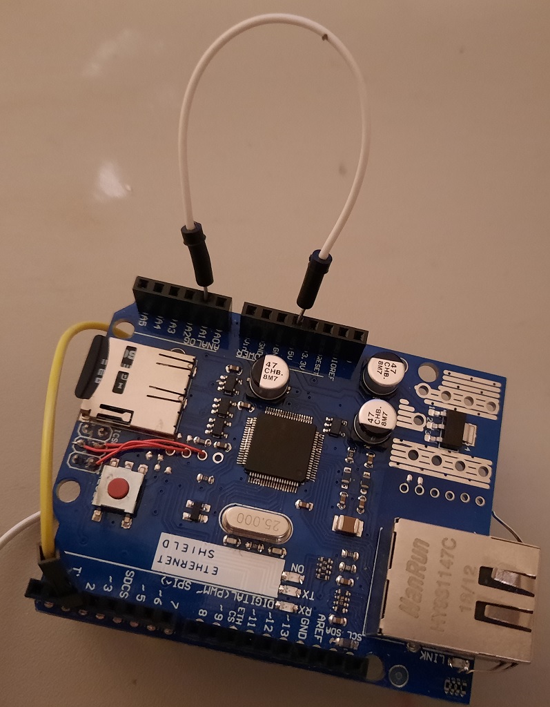
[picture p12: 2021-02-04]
img/A15V.jpg

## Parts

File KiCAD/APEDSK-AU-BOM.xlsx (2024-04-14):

Refercence | Type | Volume | Notes
C1-C7 | 100N ceramic | 7
D1 | 3mm LED | 1
D2 | 1N5711 | 1 | Schottky; 1N4148 should work as well
J1 |  | 1 | Industrial Card Edge Slot Socket Connector 22x2P 44P 2.54mm 0.1" 3A * 240-44
P1 |  | 1 | Arduino stackable header pack (long version)
P2 |  | 1 | Arduino stackable header pack (long version)
P3 |  | 1 | Arduino stackable header pack (long version)
P4 |  | 1 | Arduino stackable header pack (long version)
R1-R3 | 5.1K | 3 | any reasonably close value should work fine (i.e. 4.7K)
R4 | 330R | 1
R5 | 1K | 1 | wire link does work as well
U1 | 74LS245 | 1 | 74HCT245 should work as well (not tested)
U2, U3 | 74HCT541 | 2 | 74LS541 should work as well
U4 | GAL16V8 | 1
U5, U6 | 74HC595 | 2
U7 | IS61C512-20M | 1

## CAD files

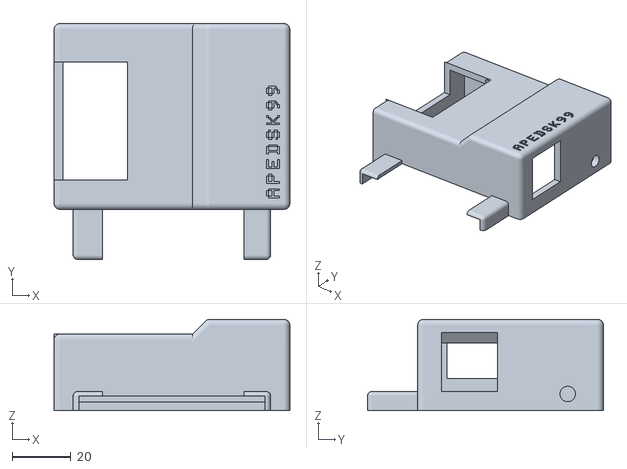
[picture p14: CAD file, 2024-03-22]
Case/APEDSK99 Top 2024 Fix.stl
80.1 x 80.0 x 31.0

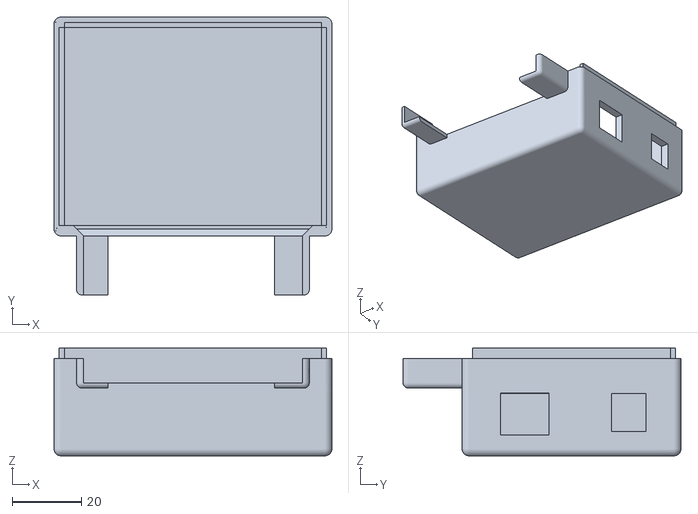
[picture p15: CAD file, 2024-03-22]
Case/APEDSK99 Bottom 2024 Fix.stl
80.0 x 80.0 x 31.0

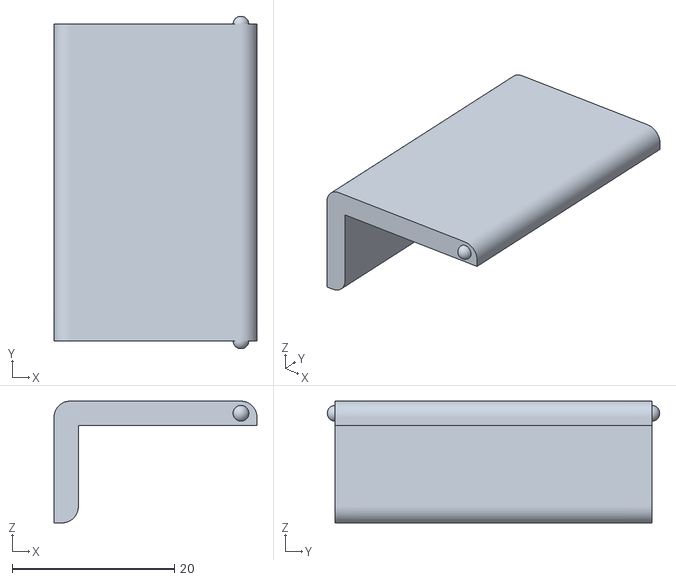
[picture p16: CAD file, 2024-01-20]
Case/APEDSK99 Lid.stl
25.0 x 41.0 x 15.0

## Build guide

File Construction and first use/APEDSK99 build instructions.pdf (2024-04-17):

OK, you decided to build one yourself; great!

Putting the APEDSK99 shield together is straightforward. No risk of sneezing ruining your SMD day and it can be put together by anybody with basic soldering skills.

You will need a suitable programmer to program the GAL with the supplied PLD file; alternatively I can send you a programmed one.

The KiCad files can be sent to your favourite online PCB maker (I use PCB Prototype & PCB Fabrication Manufacturer - JLCPCB (https://jlcpcb.com/) )

The three things that need a little bit of attention are:

### 1. Mounting the edge connector

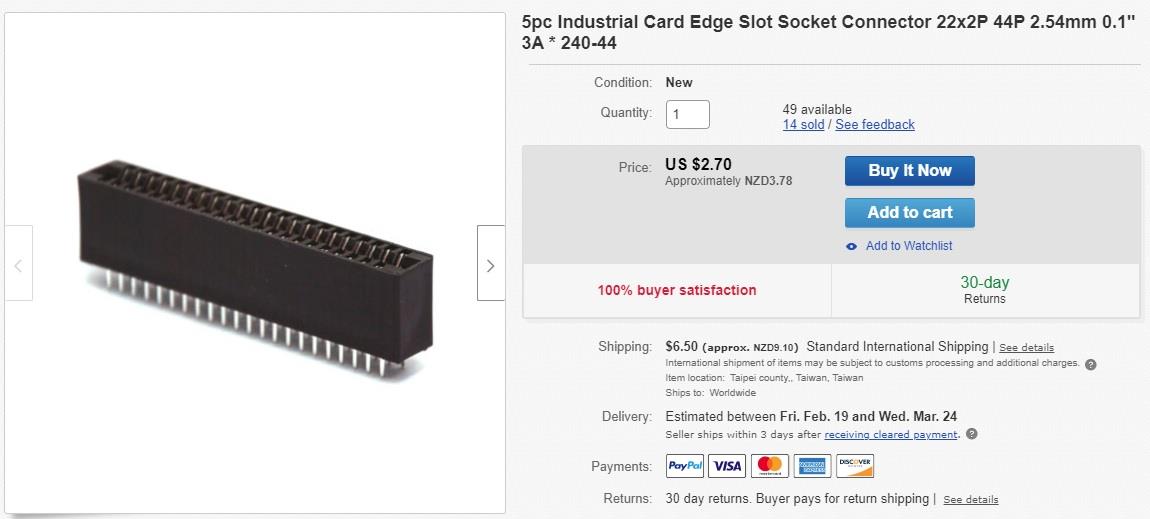
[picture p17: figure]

The bottom row of pins need to be bent 90 degrees downwards and the top row bent ~45 degrees upwards:

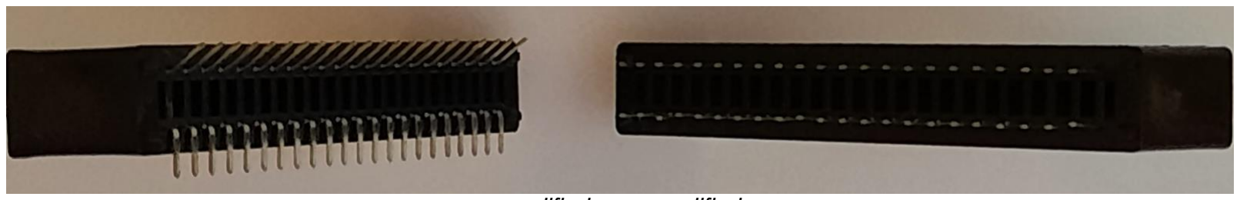
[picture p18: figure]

modified vs unmodified

I use the edge of my desk for bending but you could also use a steel ruler or needle nose pliers.

Next, rough up both the bottom side of the connector housing and the PCB area it will sit on with Scotchbrite, sandpaper etc. Painters tape is your friend here:

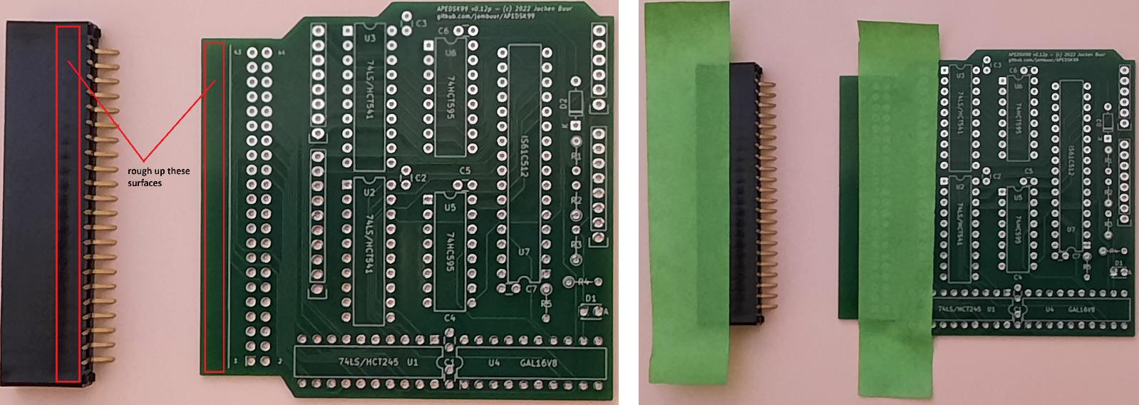
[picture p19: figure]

Clean the 2 surfaces and apply dots of superglue across the length of 1 area. Line up the bottom connector pins with the row of PCB holes marked 1-43 and press the connector firmly on the PCB, making sure all connector pins stick through to the soldering side. After clamping it for a bit to let the glue dry, the bottom row pins can now be soldered. The top row pins are soldered to the PCB via a suitable length of standard header:

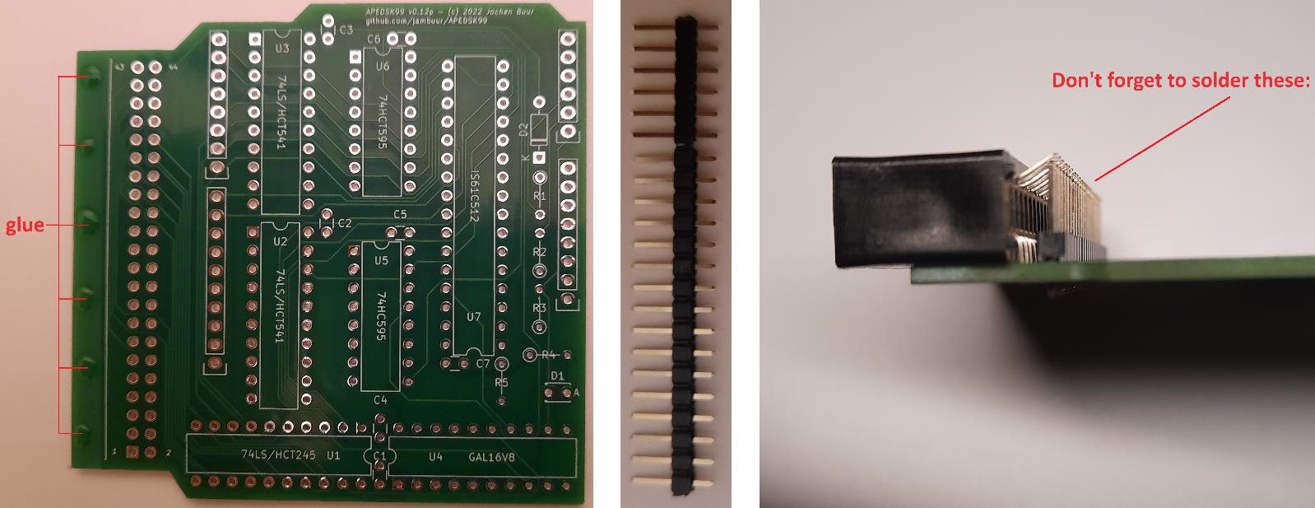
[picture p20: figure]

### 2. Installing the RAM IC

The initial APEDSK99 version used a slim line 8Kx8 RAM and little did I know that the eventual 32Kx8 RAM would not be so slim line. I decided against a major PCB redesign so you have to make the RAM fit. This is not that difficult:

(1) Bend the pins at sharp angle under the chip and then bend the very end of the pins back straight (needle nose pliers).
(2) Without too much fiddling the IC will fit the PCB hole pattern. Notice that because you’re pushing down on the IC, the pins will likely become bow-shaped. You could solder the IC like this and it will be perfectly fine.
(3) However, you can get a bit more pin sticking through: if you push down on the IC while at the same time pushing against the bowed-out bit of a pin with a small screwdriver you will restore the (1) shape

Alternatively, you could apply the above procedure to an IC socket and then mount the RAM if you worried about damaging the RAM pins.

The Arduino shield sandwich is attached to the TI I/O port. I suggest you use some sort of padding between the Arduino UNO at the bottom and your desk to prevent the stack from flapping in the breeze. Although APEDSK99 works fine without it, I have designed a suitable case for it; see my GitHub page for pics and the 3D design files.

One other thing to note is that the Arduino stackable headers seem to come in a long and a short version (short version pictured):

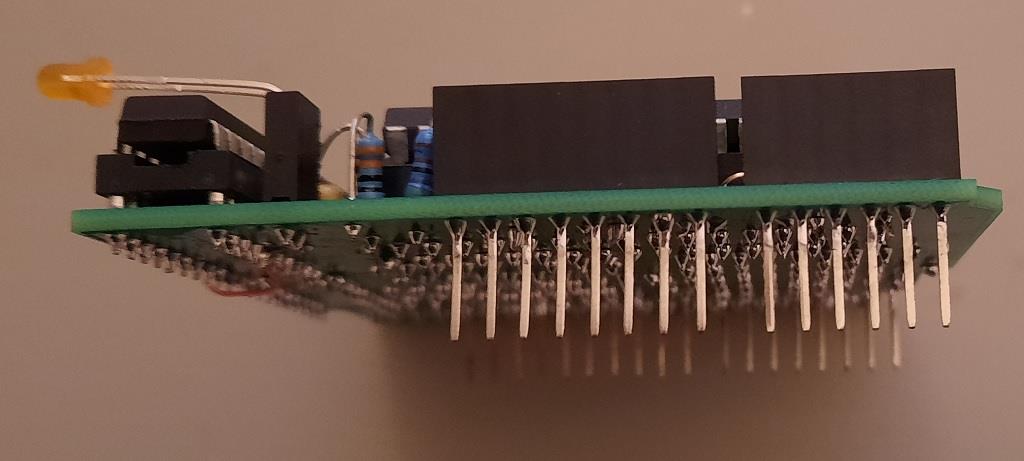
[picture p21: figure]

The short version won't let the APEDSK99 shield fit properly on the Arduino UNO as it interferes with the USB type B and power adapter connectors. Make sure you either get the long header version or use an UNO with a micro-USB connector and de-solder its power adapter connector. Also note that the short version won’t fit the current case design.

### 3. Ethernet / SD shield modifications

Depending on your Ethernet / SD shield version some minor surgery may be necessary. My version has SPI available through a separate 6 pin header only, not at the familiar D11-D14 (why? why?). If this is the case with your shield, you will need to extend the SPI signals to D11-D14 with wiring:

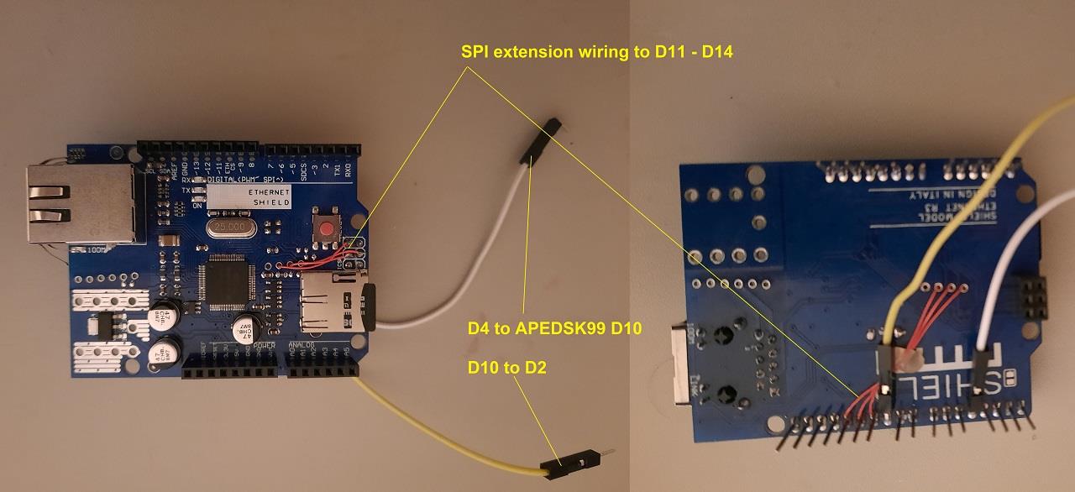
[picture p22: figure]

Most Ethernet / SD shields use D4 for the SD CS pin. This also happens to be APEDSK99 D3 (as in data bus, not in Arduino digital pin) and this combo function doesn't work. Bend D10 and D4 inwards and connect 2 jumper wires:

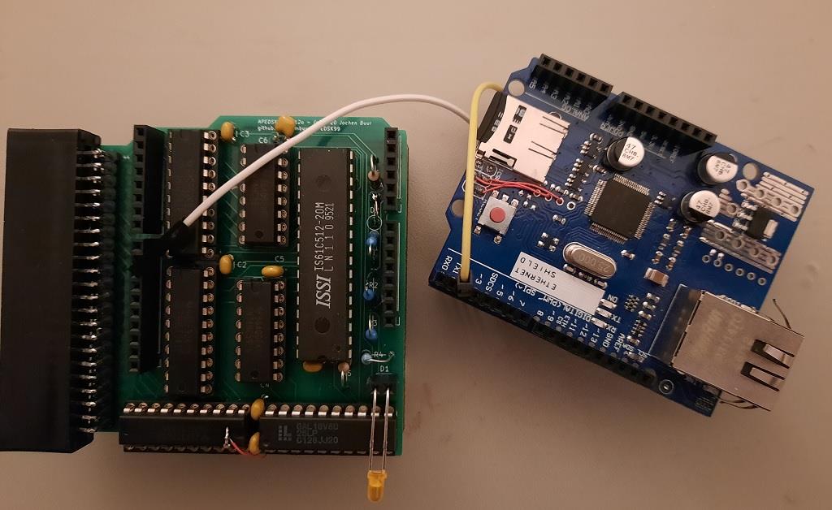
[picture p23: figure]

D10 to D2 (moves Ethernet CS to D2) and D4 to APEDSK99 D10 (moves SD CS to D10).

This is how I currently modify the Ethernet shield, I have found this the easiest and quickest way.
The final piece of heat shrink tubing on the ICSP connector is important to keep the wires from sliding out over time (as they will be upside down):

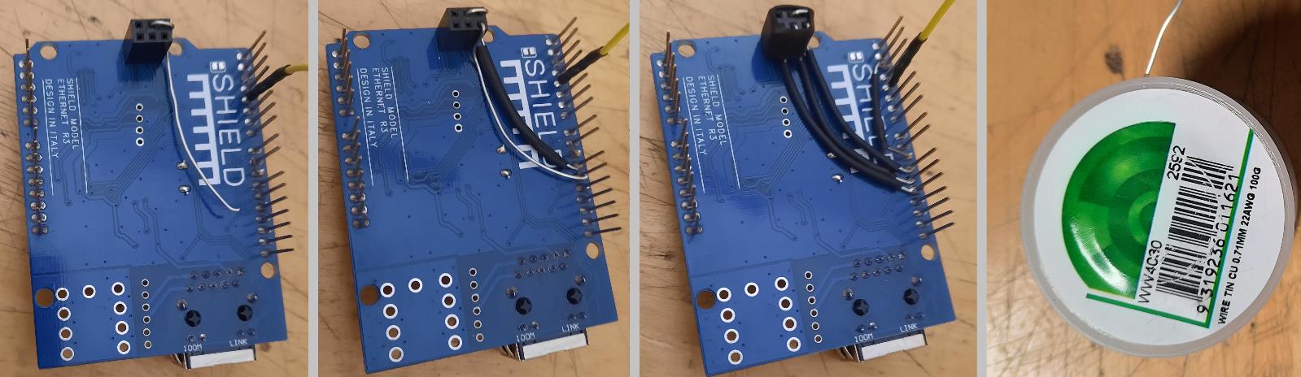
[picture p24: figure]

You don’t have to solder these connections, you could use standard Arduino jumper wires going from the ICSP connector to the topside Arduino interconnects.

An Italian TI enthusiast used plastic cable wraps with an iron core; very smart.

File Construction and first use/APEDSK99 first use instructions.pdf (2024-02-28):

GitHub repository: https://github.com/jambuur/APEDSK99
Dear TI enthusiast,

Thanks for choosing APEDSK99! I hope you will get as much pleasure out of using it as I do.

Please check the below to get APEDSK99 up and running as quickly and smoothly as possible:

- Have a read of the APEDSK99 GitHub page to learn about its quirks and features
- Program your Arduino UNO with the latest APEDSK99 software from the GitHub repository. You will find there are specific (versions of) libraries provided you will need to install within your Arduino IDE. Without these libraries the software won’t compile or will be too large to fit within the Arduino’s memory.
- Fit the APEDSK99 to the Arduino, pushing it all the way down and making sure all pins are connected
- Prepare a SD card with the contents from the GitHub repository and insert into the Ethernet Shield reader slot
- Test APEDSK99 by applying power to the Arduino. The LED should briefly flash, and this should be repeatable by pressing the Ethernet shield reset button. If the LED flashes a pattern:
- Flash: SD Card fault/not ready. Make sure if the SD card is fully inserted and is readable on another device. Although I haven’t specifically experienced it myself with APEDSK99, SD cards can be temperamental. Try a different SD card if you can.
- Flash-Flash: can't read DSR binary image (/xxxxxxxx.DSR). Check if the SD card has a proper DSR file in the root.
- Flash-Flash-Flash: no valid DSR header (>AA) at DSR RAM >4000. This could point to a hardware problem. Check if the power-up routine gets executed (see above). Check with a debugger (Easybug etc) if you can see data from >4000 onwards, specifically if you see the >AA02 DSR signature at >4000. If you don’t see any data (so all >00’s or >FF’s), APEDSK99 is not recognised. Make sure all shields are properly fitted together, the I/O connector is pushed in all the way and you have a suitable power connection.

If all is well, remove power and continue below; if all is not well please get in touch (see below).

- Thoroughly clean the TI’s I/O port before you attach APEDSK99. Use something like a cotton swab with isopropyl alcohol or similar on top and bottom contacts. Oxidised contacts can definitely spoil the fun.
- Handle APEDSK99 by gripping the middle shield only. Especially when first used, the APEDSK99 I/O connector is rather stiff and will require some force to push in place or remove. Putting force on the Arduino or Ethernet shield can damage the shield interconnects. You will find it easiest to wiggle APEDSK99 in place.
- Turn on your TI.
- Apply power to APEDSK99, wait for the LED to go off and then <FCTN><QUIT> your TI. You should see a (very) brief flash of the LED, showing the DSR powerup routine has been executed.
- Go into BASIC, type “CALL AHLP” and press <ENTER>. The APEDSK99 help screen should pop up.
- To configure APEDSK99 for your network and be able to use NTP and FTP you will need the IP address(es) of your FTP and NTP host(s). I suggest trying these addresses on a PC etc before you configure APEDSK99 as the latter doesn’t provide any network testing/debugging function. This is especially important when using addresses outside the local subnet as you will be relying on some forwarding/routing service to reach these hosts.

Connect an Ethernet cable to the Ethernet shield, it should show some LED activity.

Mount the configuration disk in DSK1 and run the following in TI BASIC (not EXBAS):

- CALL MDSK(1,”AD99SUP”)
- OLD DSK1.ACFG
- RUN

Follow the prompts and see if you get the proper date and time displayed when finished.

Needless to say, if you run into unexpected problems, can’t get APEDSK99 to behave or are otherwise unhappy with it just email me at burell@hotmail.com or ping me on AtariAge (JJB) and I will sort it out for you.

Don’t hesitate to ask any questions or provide feedback, chances are it will improve the APEDSK99 experience for other users too.

Thanks again,

Jochen

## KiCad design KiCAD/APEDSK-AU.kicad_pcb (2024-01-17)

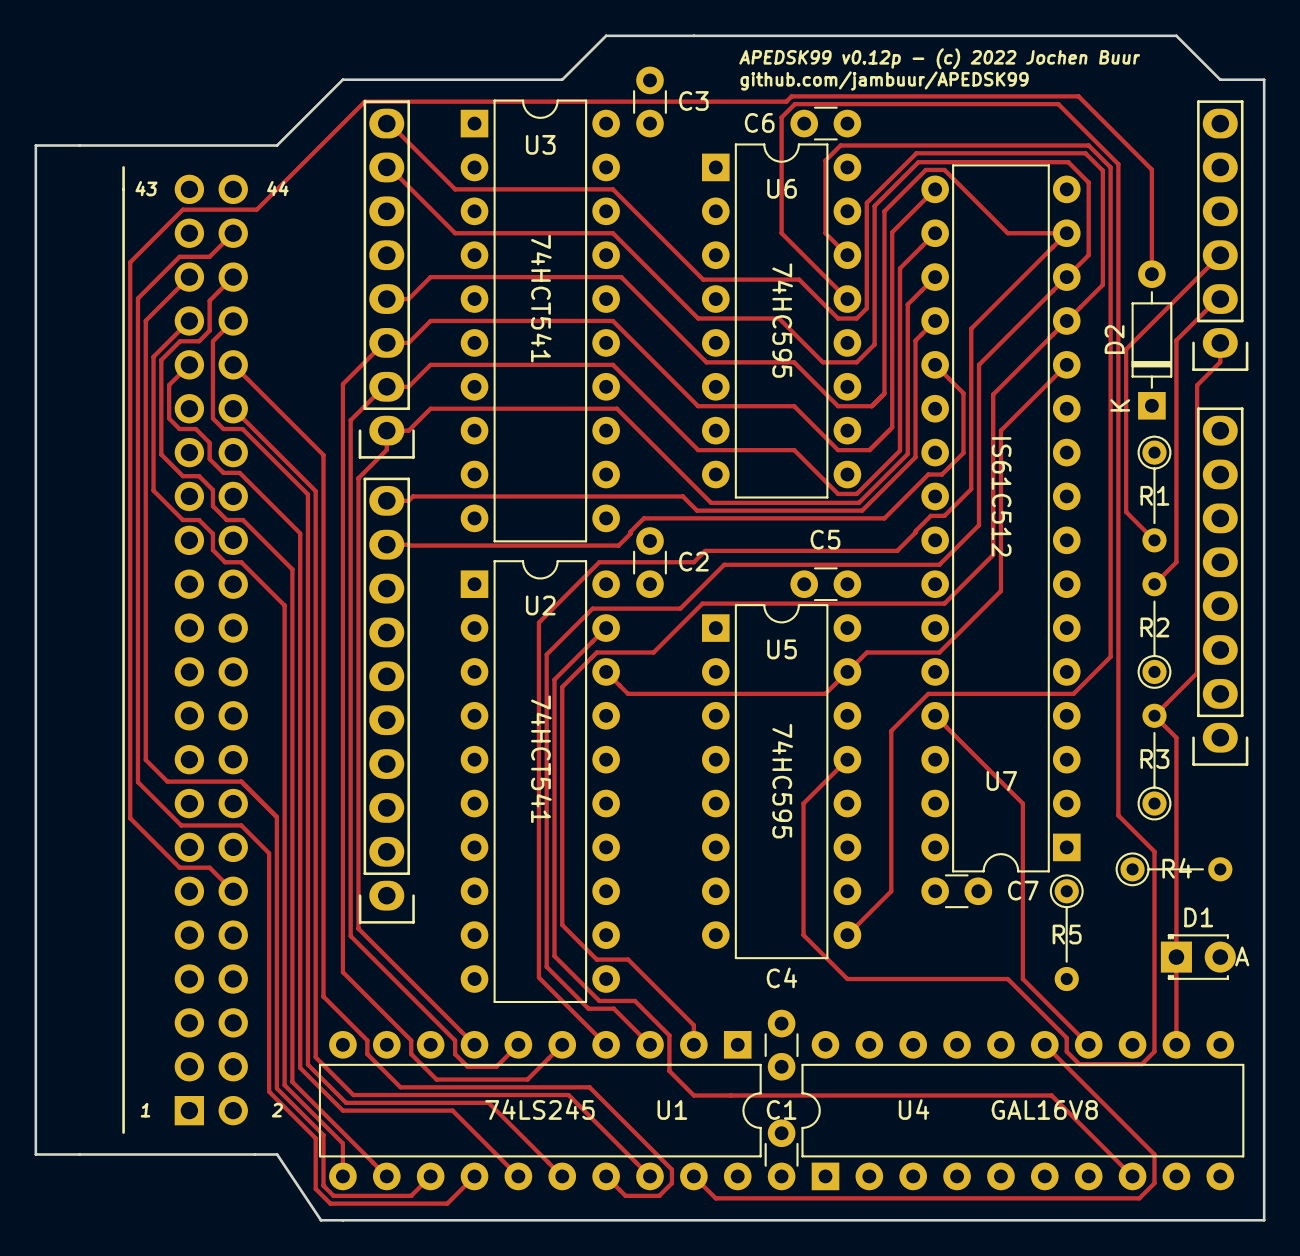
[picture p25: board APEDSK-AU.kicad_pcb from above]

Board: 4 copper layers, 71.1 x 68.6 mm, 26 parts (1 on the bottom side), 45 nets.

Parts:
C1, C2, C3, C4, C5, C6, C7: 100N; C_Disc_D3.0mm_W1.6mm_P2.50mm
D1: ~CE; LED_D1.8mm_W3.3mm_H2.4mm
D2: 1N4148; D_DO-35_SOD27_P7.62mm_Horizontal
J1: 240-44-44Pins; PinHeader_2x22_P2.54mm_Vertical
P1: Power; Socket_Strip_Arduino_1x08
P2: Analog; Socket_Strip_Arduino_1x06
P3: Digital; Socket_Strip_Arduino_1x10
P4: Digital; Socket_Strip_Arduino_1x08
R1, R2, R3: 5.1K; R_Axial_DIN0204_L3.6mm_D1.6mm_P5.08mm_Vertical
R4: 330R; R_Axial_DIN0204_L3.6mm_D1.6mm_P5.08mm_Vertical
R5: 1K; R_Axial_DIN0204_L3.6mm_D1.6mm_P5.08mm_Vertical
U1: 74LS245; DIP-20_W7.62mm
U2, U3: 74LS541; DIP-20_W7.62mm
U4: GAL16V8; DIP-20_W7.62mm
U5, U6: 74HC595; DIP-16_W7.62mm
U7: IS61C512-20M; DIP-32_W7.62mm

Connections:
+5V: C1.2, C2.1, C3.1, C4.1, C5.1, C6.1, C7.1, P1.5, R1.1, R2.1, R3.1, R4.1, U1.20 (VCC), U2.20 (VCC), U3.20 (VCC), U4.20 (VCC), U5.10 (~SRCLR), U5.16 (VCC), U6.10 (~SRCLR), U6.16 (VCC), U7.30 (CE2), U7.32 (VCC)
/A0: J1.31, U3.9 (A7)
/A1: J1.30, U3.8 (A6)
/A2: J1.20, U3.7 (A5)
/A3: J1.10, U3.6 (A4)
/A4: J1.7, U3.5 (A3)
/A5: J1.5, U3.4 (A2)
/A6: J1.29, U3.3 (A1)
/A7: J1.17, U3.2 (A0)
/A8: J1.14, U2.9 (A7)
/A9: J1.18, U2.8 (A6)
/A10: J1.6, U2.7 (A5)
/A11: J1.8, U2.6 (A4)
/A12: J1.11, U2.5 (A3)
/A13: J1.15, U2.4 (A2)
/A14: J1.16, U2.3 (A1)
/A15: J1.19, U2.2 (A0)
/AD_A0: U2.11 (Y7), U2.12 (Y6), U2.13 (Y5), U2.14 (Y4), U2.15 (Y3), U2.16 (Y2), U2.17 (Y1), U2.18 (Y0), U4.5 (I5), U5.1 (QB), U5.2 (QC), U5.3 (QD), U5.4 (QE), U5.5 (QF), U5.6 (QG), U5.7 (QH), U5.15 (QA), U7.5 (A7), U7.6 (A6), U7.7 (A5), U7.8 (A4), U7.9 (A3), U7.10 (A2), U7.11 (A1), U7.12 (A0)
/AD_A10: U3.11 (Y7), U3.12 (Y6), U3.13 (Y5), U3.14 (Y4), U3.15 (Y3), U3.16 (Y2), U3.17 (Y1), U3.18 (Y0), U4.2 (I2), U4.3 (I3), U4.4 (I4), U6.1 (QB), U6.2 (QC), U6.3 (QD), U6.4 (QE), U6.5 (QF), U6.6 (QG), U6.7 (QH), U6.15 (QA), U7.3 (A14), U7.4 (A12), U7.23 (A10), U7.25 (A11), U7.26 (A9), U7.27 (A8), U7.28 (A13), U7.31 (A15)
/AD_D0: P3.9, P3.10, P4.1, P4.2, P4.3, P4.4, P4.7, P4.8, U1.2 (A0), U1.3 (A1), U1.4 (A2), U1.5 (A3), U1.6 (A4), U1.7 (A5), U1.8 (A6), U1.9 (A7), U7.13 (D0), U7.14 (D1), U7.15 (D2), U7.17 (D3), U7.18 (D4), U7.19 (D5), U7.20 (D6), U7.21 (D7)
/CE_245: U1.19 (CE), U4.15 (IO5)
/CLOCK: P2.4, U5.11 (SRCLK), U6.11 (SRCLK)
/D0: J1.37, U1.11 (B7)
/D1: J1.40, U1.12 (B6)
/D2: J1.39, U1.13 (B5)
/D3: J1.42, U1.14 (B4)
/D4: J1.35, U1.15 (B3)
/D5: J1.38, U1.16 (B2)
/D6: J1.36, U1.17 (B1)
/D7: J1.34, U1.18 (B0)
/DBIN: J1.9, U1.1 (A->B)
/DS: P2.6, U5.14 (SER)
/LATCH: P2.5, U5.12 (RCLK), U6.12 (RCLK)
/READY: D2.2 (A), J1.12
/~AD_CE: D1.1 (K), P2.1, R3.2, U4.12 (IO8), U7.22 (~CE1)
/~AD_WE: P2.3, R1.2, U4.14 (IO6), U7.29 (~WE)
/~AR_BUF: D2.1 (K), P4.5, U5.13 (~OE), U6.13 (~OE)
/~MEMEN: J1.32, U4.7 (I7)
/~TIBUF: P2.2, R2.2, U2.1 (G1), U2.19 (G2), U3.1 (G1), U3.19 (G2), U4.8 (I8)
/~TI_INT: P4.6, R5.1
/~WE: J1.26, U4.6 (I6)
GND: C1.1, C2.2, C3.2, C4.2, C5.2, C6.2, C7.2, J1.21, J1.23, J1.25, J1.27, P1.6, P1.7, U1.10 (GND), U2.10 (GND), U3.10 (GND), U4.1 (I1/CLK), U4.9 (I9), U4.10 (GND), U4.11 (I10/~OE), U5.8 (GND), U6.8 (GND), U7.16 (GND), U7.24 (~OE)
unnamed: D1.2 (A), R4.2
unnamed: R5.2, U4.13 (IO7)
unnamed: U5.9 (QH'), U6.14 (SER)

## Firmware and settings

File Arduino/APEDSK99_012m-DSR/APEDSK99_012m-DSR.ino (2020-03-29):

/* APEDISK99
  This sketch emulates 3 TI99/4a disk drives. Shopping list:

  - Arduino Uno
	- SD shield (RTC optional but potentially super handy; no guarantees though)
	- APEDSK99 shield (github.com/jambuur/APEDSK99)

  The Arduino RAM interface is based on Mario's EEPROM programmer:
  github.com/mkeller0815/MEEPROMMER

  (much) faster digitalRead / Write by:
  http://masteringarduino.blogspot.com/2013/10/fastest-and-smallest-digitalread-and.html
  usage:
    pinMode( pin, INPUT );        with pinAsInput( pin );
    pinMode( pin, OUTPUT );       with pinAsOutput( pin );
    pinMode( pin, INPUT_PULLUP);  with pinAsInputPullUp( pin );
    digitalWrite( pin, LOW );     with digitalLow( pin );
    digitalWrite( pin, HIGH );    with digitalHigh( pin );
    digitalRead( pin )            with digitalState( pin )
    if( digitalState( pin ) == HIGH )  can be if( isHigh( pin ) )
    digitalState( pin ) == LOW         can be isLow( pin )

  $Author: Jochen Buur $
  $Date: Aug 2019 $
  $Revision: 0.12l $

resetFunc();  This software is freeware and can be modified, re-used or thrown away without any restrictions.

  Use this code at your own risk.
  I'm not responsible for any bad effect or damages caused by this software
*/

//-DSR generic---------------------------------------------------------------------------------- Libraries
//SPI and SD card functions
#include <SPI.h>
#include <SD.h>

//SPI card select pin
#define SPI_CS 10

//-DSR generic--------------------------------------------------------------------------------- Definitions
//faster digitalRead / digitalWrite definitions
#define portOfPin(P)\
  (((P)>=0&&(P)<8)?&PORTD:(((P)>7&&(P)<14)?&PORTB:&PORTC))
#define ddrOfPin(P)\
  (((P)>=0&&(P)<8)?&DDRD:(((P)>7&&(P)<14)?&DDRB:&DDRC))
#define pinOfPin(P)\
  (((P)>=0&&(P)<8)?&PIND:(((P)>7&&(P)<14)?&PINB:&PINC))
#define pinIndex(P)((uint8_t)(P>13?P-14:P&7))
#define pinMask(P)((uint8_t)(1<<pinIndex(P)))

#define pinAsInput(P) *(ddrOfPin(P))&=~pinMask(P)
#define pinAsInputPullUp(P) *(ddrOfPin(P))&=~pinMask(P);digitalHigh(P)
#define pinAsOutput(P) *(ddrOfPin(P))|=pinMask(P)
#define digitalLow(P) *(portOfPin(P))&=~pinMask(P)
#define digitalHigh(P) *(portOfPin(P))|=pinMask(P)
#define isHigh(P)((*(pinOfPin(P))& pinMask(P))>0)
#define isLow(P)((*(pinOfPin(P))& pinMask(P))==0)
#define digitalState(P)((uint8_t)isHigh(P))

//!!!APEDSK99 board version v0.12m 2020
//74HC595 shift-out definitions
#define CLOCK     17  //PC3
#define LATCH     18  //PC4
#define DS        19  //PC5

//IO lines for Arduino RAM control
#define CE  14  //PC0  LED flashes for both Arduino CE* and TI MBE*
#define WE  16	//PC2

//IO lines for TI99/4a control
#define TI_READY       3  //PD0; TI READY line + enable/disable 74HC595 shift registers
#define TI_INT      	 2  //PD2; 74LS138 interrupt (MBE*, WE* and A15) 
#define TI_BUFFERS    15  //PC1; 74LS541 buffers enable/disable

//error blinking parameters: on, off, delay between sequence
#define LED_ON       500
#define LED_OFF      250
#define LED_REPEAT  1500

//-DSR generic---------------------------------------------------------------------------------- Hardware functions

//short delay function to let bus/signals settle. 
//6us is the minumum stable value on my TI but your mileage may vary
inline void NOP() __attribute__((always_inline));
void NOP() {
  delayMicroseconds(8);
}

//databus:
//D0,0,PD0 / D1,1,PD1 / D2,4,PD4 / D3,5,PD5 / D4,6,PD6 / D5,7,PD7 / D6,8,PD8 / D7,9,PD9
//switch databus to INPUT state for reading from RAM

void dbus_in() {
  DDRD  &= B00001100;  //set PD7-PD4 and PD1-PD0 to input (D5-D2, D1-D0)
  PORTD &= B00001100;  //initialise input pins
  DDRB  &= B11111100;  //set PB1-PB0 to input (D7-D6)
  PORTB &= B11111100;  //initialise input pins
}

//switch databus to OUTPUT state for writing to RAM
void dbus_out() {
  DDRD  |= B11110011;  //set PD7-PD4 and PD1-PD0 to output (D5-D2, D1-D0)
  DDRB  |= B00000011;  //set PB1-PB0 to output (D7-D6)
}

//disable Arduino control bus; CE* and WE* both HighZ
void dis_cbus() {
  pinAsInput(CE);
  pinAsInput(WE);
}

//enable Arduino control bus; CE* and WE* both HIGH due to 5.1K pull-ups
void ena_cbus() {
  pinAsOutput(CE);
  pinAsOutput(WE);
}

//read a byte from the databus
byte dbus_read()
{
  NOP();				                            //long live the Logic Analyzer
  return ( ((PIND & B00000011)     ) +      //read PD1,PD0 (D1-D0)
           ((PIND & B11110000) >> 2) +      //read PD7-PD3 (D5-D1)     
           ((PINB & B00000011) << 6) );     //read PB1-PBO (D7-D6)
}

//place a byte on the databus
void dbus_write(byte data)
{
  PORTD |= ((data     ) & B00000011);       //write PD1 (D0)
  PORTD |= ((data << 2) & B11110000);       //write PD7-PD3 (D5-D1)
  PORTB |= ((data >> 6) & B00000011);       //write PB1-PBO (D7-D6)
}

//shift out the given address to the 74HC595 registers
void set_abus(unsigned int address)
{
  //disable latch line
  digitalLow(LATCH);
  //clear data pin
  digitalLow(DS);

  //OK, repetitive, slightly ugly code but ... 1.53x as fast as the more elegant for() - if() - else()
  //for every address bit (13 bits to address 8Kbytes) set:
  //CLOCK -> LOW, address bit -> DS bit, CLOCK -> HIGH to shift and DS bit -> LOW to prevent bleed-through
  digitalLow(CLOCK);
  PORTC |= ( (address >>  7) & B00100000); digitalHigh(CLOCK); digitalLow(DS); //A12
  digitalLow(CLOCK);
  PORTC |= ( (address >>  6) & B00100000); digitalHigh(CLOCK); digitalLow(DS); //A11
  digitalLow(CLOCK);
  PORTC |= ( (address >>  5) & B00100000); digitalHigh(CLOCK); digitalLow(DS); //A10
  digitalLow(CLOCK);
  PORTC |= ( (address >>  4) & B00100000); digitalHigh(CLOCK); digitalLow(DS); //A9
  digitalLow(CLOCK);
  PORTC |= ( (address >>  3) & B00100000); digitalHigh(CLOCK); digitalLow(DS); //A8
  digitalLow(CLOCK);
  PORTC |= ( (address >>  2) & B00100000); digitalHigh(CLOCK); digitalLow(DS); //A7
  digitalLow(CLOCK);
  PORTC |= ( (address >>  1) & B00100000); digitalHigh(CLOCK); digitalLow(DS); //A6
  digitalLow(CLOCK);
  PORTC |= ( (address      ) & B00100000); digitalHigh(CLOCK); digitalLow(DS); //A5
  digitalLow(CLOCK);
  PORTC |= ( (address <<  1) & B00100000); digitalHigh(CLOCK); digitalLow(DS); //A4
  digitalLow(CLOCK);
  PORTC |= ( (address <<  2) & B00100000); digitalHigh(CLOCK); digitalLow(DS); //A3
  digitalLow(CLOCK);
  PORTC |= ( (address <<  3) & B00100000); digitalHigh(CLOCK); digitalLow(DS); //A2
  digitalLow(CLOCK);
  PORTC |= ( (address <<  4) & B00100000); digitalHigh(CLOCK); digitalLow(DS); //A1
  digitalLow(CLOCK);
  PORTC |= ( (address <<  5) & B00100000); digitalHigh(CLOCK); digitalLow(DS); //A0

  //stop shifting
  digitalLow(CLOCK);
  //enable latch and set address
  digitalHigh(LATCH);
}

//read a byte from RAM address
byte Rbyte(unsigned int address)
{
  byte data = 0x00;
  //set address bus
  set_abus(address);
  //set databus for reading
  dbus_in();
  //enable RAM chip select
  digitalLow(CE);
  //get databus value
  data = dbus_read();
  //disable RAM chip select
  digitalHigh(CE);
  return data;
}

//write a byte to RAM address
void Wbyte(unsigned int address, byte data)
{
  //set address bus
  set_abus(address);
  //set databus for writing
  dbus_out();
  //set data bus value
  dbus_write(data);
  //enable write
  digitalLow(WE);
  //enable RAM chip select
  digitalLow(CE);
  //disable chip select
  digitalHigh(CE);
  //disable write
  digitalHigh(WE);
  //set databus to (default) input state
  dbus_in();
}

//enable TI I/O, disable Arduino shift registers and control bus
//INLINE: need for speed
inline void TIgo() __attribute__((always_inline));
void TIgo()
{
  dis_cbus();               //cease Arduino RAM control
  pinAsOutput(TI_BUFFERS);  //enable 74LS541's 
  EIFR = bit (INTF0);       // clear flag for interrupt 0 
  EIMSK |= B00000001;       //enable INT0
  pinAsInput(TI_READY);     //switch to HIGH: disables 74HC595's and wakes up TI
}

//disable TI I/O, enable Arduino shift registers and control bus
//INLINE: need for speed in ISR
inline void TIstop() __attribute__((always_inline));
void TIstop() {
  EIMSK &= B11111110;         //disable INT0
  pinAsOutput(TI_READY);      //bring READY line LOW (halt TI)
  NOP();                      //long live the Logic Analyzer
  pinAsInput(TI_BUFFERS);     //disables 74LS541's    
  ena_cbus();                 //Arduino in control of RAM
}

//-DSR generic---------------------------------------------------------------------------------------- Hardware Error handling

//flash error code:
//  flash                   : SPI / SD Card fault/not ready
//  flash-flash             : can't read DSR binary image (/APEDSK99.DSR)
//  flash-flash-flash       : no valid DSR header (>AA) at DSR RAM >0000
void eflash(byte error)
{
  //"no APEDSK99 for you" but let user still enjoy a vanilla TI console
  digitalHigh(TI_READY);	    //enable TI but ...
  //... enable Arduino CE* for flashing the error code
  pinAsOutput(CE);
  //error routine: stuck in code flashing loop until reset
  while (true) { 
    for (byte flash = 0; flash < error; flash++)
    {
      //set RAM CE* LOW, turns on LED
      digitalLow(CE);
      //LED is on for a bit
      delay(LED_ON);

      //turn it off
      digitalHigh(CE);
      //LED is off for a bit
      delay(LED_OFF);
    }
    //allow human error interpretation
    delay(LED_REPEAT); 
  }
}

//-APEDSK99 specific-------------------------------------------------------------------------- FD1771 emu: variables and functions

//Status Register bits
#define NOTREADY  0x80
#define PROTECTED 0x40
#define NOERROR   0x00

//"Force Interrupt" command
#define FDINT 0xD0

//"disk" characteristics
#define NRTRACKS   40   //# of tracks/side
#define NRSECTS     9   //# sectors/track
#define NRBYSECT  256   //# bytes/sector

//DOAD file name handling (DSKx 1-3 (2 bytes) + 8 bytes/characters)
#define DTCDSK  0x1FD6
//APEDSK99-specific Command Register (TI BASIC CALL support)
#define ACOMND  0x1FE8
//R6 counter value to detect read access in sector, ReadID and track commands
#define RDINT   0x1FEA
//TI BASIC screen bias
#define TIBias  0x60
//pulling my hair out trouleshooting address
#define aDEBUG 0x1EE0

//CRU emulation bytes + FD1771 registers
#define CRURD   0x1FEC  //emulated 8 CRU input bits           (>5FEC in TI99/4a DSR memory block); not used but possible future use
//B00001111: DSK3 (0x06), DSK2 (0x04), DSK1 (0x02), side 0/1
#define CRUWRI  0x1FEE  //emulated 8 CRU output bits          (>5FEE in TI99/4a DSR memory block)
#define RSTAT   0x1FF0  //read FD1771 Status register         (>5FF0 in TI99/4a DSR memory block)
#define RTRACK  0x1FF2  //read FD1771 Track register          (>5FF2 in TI99/4a DSR memory block)
#define RSECTR  0x1FF4  //read FD1771 Sector register         (>55F4 in TI99/4a DSR memory block)
#define RDATA   0x1FF6  //read FD1771 Data register           (>5FF6 in TI99/4a DSR memory block)
#define WCOMND  0x1FF8  //write FD1771 Command register       (>5FF8 in TI99/4a DSR memory block)
#define WTRACK  0x1FFA  //write FD1771 Track register         (>5FFA in TI99/4a DSR memory block)
#define WSECTR  0x1FFC  //write FD1771 Sector register        (>5FFC in TI99/4a DSR memory block)
#define WDATA   0x1FFE  //write FD1771 Data register          (>5FFE in TI99/4a DSR memory block)

//DSKx file pointers
File DSK[4];  //file pointers to DOAD's

//flags for "drives" (aka DOAD files) available
boolean aDSK[4] = {false, false, false, false};                                                 //disk availability
String  nDSK[4] = {"x", "/DISKS/_APEDSK1.DSK", "/DISKS/_APEDSK2.DSK", "/DISKS/_APEDSK3.DSK"};	  //DOAD file names; startup defaults
boolean pDSK[4] = {false, false, false, false};                                                 //DOAD write protect status aka the adhesive tab
byte    cDSK    = 0;                                                                            //current selected DSK

//various storage and flags for command interpretation and handling
volatile boolean FD1771   = false;  //interrupt routine flag: new or continued FD1771 command
byte FCcmd                = 0;      //current FD1771 command
byte FLcmd                = 0;      //last FD1771 command
boolean FNcmd             = false;  //flag new FD1771 command
byte ACcmd                = 0;      //current APEDSK99 command
byte ALcmd                = 0;      //last APEDSK99 command
boolean ANcmd             = false;  //flag new APEDSK99 command
unsigned long Dbtidx      = 0;      //absolute DOAD byte index
unsigned long Sbtidx      = 0;	    // R/W sector/byte index counter
byte Ssecidx              = 0;      // R/W sector counter
byte cTrack               = 0;      //current Track #
byte nTrack               = 0;      //new Track # (Seek)
boolean cDir              = HIGH;   //current step direction, step in(wards) towards track 39 by default
String DOAD               = "";	    //TI BASIC CALL support (used by CDSK and SDSK)
char cDot		              = "";	    //"." detection in MSDOS 8.3 format
byte vDEBUG               = 0;      //generic pulling my hair out trouleshooting variable
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
void loop() {
 
  //check if flag has set by interrupt routine
  if (FD1771) {
    
    //read Command Register, stripping the unnecessary floppy bits but keeping command nybble
    FCcmd = Rbyte(WCOMND) & B11110000;

    //the FD1771 "Force Interrupt" command is used to stop further command execution
    if ( FCcmd != FDINT ) { //do we need to do anything?
      
      FNcmd = (FCcmd != FLcmd);                             //new or continue previous FD1771 command?
      if (FNcmd) {                                          //new command?
        FLcmd = FCcmd;                                      //yes; remember new command for next compare
      }
      //----------------------------------------------------------------------------------------- FD1771 Seek / Step
      if ( FCcmd < 0x80 ) {                                 //step/seek commands?

        cTrack = Rbyte(WTRACK);                             //read current Track #
        nTrack = Rbyte(WDATA);                              //read new Track # (Seek)

        switch(FCcmd) {
         
          case 0x00:					                              //Restore            
          { 
	          cTrack = 0;                                     //reset cTrack so Track Registers will be cleared after switch{}
            FDrstr();
          }
          break;

          case 0x10:					                              //Seek
          {
            cTrack = nTrack;                                //prepare to update Track Register
	          cDir = (nTrack > cTrack);                       //set direction: HIGH=track # increase, LOW=track # decrease
          } 
          break;
            
          case 0x20:                                        //Step
          case 0x30:                                        //Step+T
          {
            if ( cDir == LOW ) {
              FCcmd = 0x70;				                          //execute Step-Out+T
            } else {
              FCcmd = 0x50;				                          //execute Step-In+T
	          }
          }
          case 0x40:                                        //Step-In
          case 0x50:                                        //Step-In+T
          {
            if ( cTrack < NRTRACKS ) {			                //any tracks left to step to?
              cTrack++;                                     //yes; increase Track #
              cDir = HIGH;                                  //set stepping direction towards last track 
            }
          }
          break;

          case 0x60:                                        //Step-Out
          case 0x70:                                        //Step-Out+T
          {
            if ( cTrack > 0 ) {				                      //any tracks left to step to?
              cTrack--;                                     //decrease Track #
              cDir = LOW;                                   //set stepping direction towards track 0
            }
          }
          break;
            
        } //end switch FCcmd
        Wbyte(WTRACK, cTrack);				                      //update Track Register
	      Wbyte(RTRACK, cTrack);                              //sync Track Registers
        noExec();                                           //prevent multiple step/seek execution                                        

      // end FCcmd < 0x80
      } else {  // read/write commands
        
        //----------------------------------------------------------------------------------------- FD1771 R/W commands: prep
        if ( FNcmd ) {					                                //new command prep
          cDSK = ( Rbyte(CRUWRI) >> 1) & B00000011;             //yes do some prep; determine selected disk
          if ( aDSK[cDSK] ) {                                   //is selected disk available?
            Wbyte(RSTAT, NOERROR);                              //reset possible "Not Ready" bit in Status Register
            if ( FCcmd == 0xE0 || FCcmd == 0xF0 ) {             // R/W whole track?
              Wbyte(WSECTR, 0x00);                              //yes; start from sector 0
            }
            DSK[cDSK] = SD.open(nDSK[cDSK], O_READ | O_WRITE);  //open SD DOAD file
            Dbtidx = cDbtidx();                                 //calc absolute DOAD byte index
            DSK[cDSK].seek(Dbtidx);                             //set to first absolute DOAD byte for R/W
          } else {
            if ( cDSK != 0 ) {                                  //ignore DSK0; either DSK1, DSK2 or DSK3 is not available
              Wbyte(RSTAT, NOTREADY);                           //set "Not Ready" bit in Status Register
              FCcmd = FDINT;                                    //exit 
            }
          }
        }
        
        //----------------------------------------------------------------------------------------- FD1771 R/W commands
        switch (FCcmd) {  //switch R/W commands

          case 0xD0:
          {
            noExec();
          }
          break;

          case 0x80:                                      //read sector
	        case 0x90:                                      //read multiple sectors
	        case 0xE0:                                      //read track		
          {
            RWsector( true );
          }
          break;

          case 0xA0:         				                      //write sector
	        case 0xB0:                                      //write multiple sectors
          case 0xF0:                                      //write track
          {
            if ( !pDSK[cDSK] ) {                          //is DOAD write protected?
              RWsector( false );                          //no; go ahead and write
            } else {
              Wbyte(RSTAT, PROTECTED);                    //yes; set "Write Protect" bit in Status Register
              FCcmd = FDINT;                              //exit      
            }
          }
          break;

        } //end R/W switch
      } //end else R/W commands

    //end we needed to do something
    } else {    

      //------------------------------------------------------------------------------------------- APEDSK99-specifc commands
      //check for APEDSK99-specfic commands
      ACcmd = Rbyte(ACOMND);
      if ( ACcmd != 0 ) {

        ANcmd = (ACcmd != ALcmd);                                             //new or continue previous APEDSK99 command?
        if (ANcmd) {                                                          //new command?
          ALcmd = ACcmd;                                                      //yes; remember new command for next compare
        }
       
        //----------------------------------------------------------------- TI BASIC PDSK(), UDSK(), CDSK(), SDSK() and FDSK()
        switch ( ACcmd ) {

          case  1:                                                            //UDSK(1):  Unprotect DSK1
          case  2:                                                            //UDSK(2):  Unprotect DSK2
          case  3:                                                            //UDSK(3):  Unprotect DSK3      
          case  5:                                                            //PDSK(1):  Protect DSK1
          case  6:                                                            //PDSK(2):  Protect DSK2
          case  7:                                                            //PDSK(3):  Protect DSK3
          {
            cDSK = ACcmd & B00000011;                                         //strip U/P flag, keep DSKx
            if ( aDSK[cDSK] ) {
              DSK[cDSK] = SD.open(nDSK[cDSK], O_READ | O_WRITE);              //open DOAD file to change write protect status 
              DSK[cDSK].seek(0x28);                                           //byte 0x28 in Volume Information Block stores APEDSK99 adhesive tab status 
              if ( ACcmd & B00000100 ) {                                      //Protect bit set?
                DSK[cDSK].write(0x50);                                        //yes; apply adhesive tab
                pDSK[cDSK] = true;
              } else {
                DSK[cDSK].write(0x20);                                        //no; remove adhesive tab
                pDSK[cDSK] = false;            
              }
            } 
            noExec();
          }
          break;
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

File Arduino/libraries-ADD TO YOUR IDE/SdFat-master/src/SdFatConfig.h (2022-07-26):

/**
 * Copyright (c) 2011-2018 Bill Greiman
 * This file is part of the SdFat library for SD memory cards.
 *
 * MIT License
 *
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
 * THE SOFTWARE IS PROVIDED "AS IS", WITHOUT WARRANTY OF ANY KIND, EXPRESS
 * OR IMPLIED, INCLUDING BUT NOT LIMITED TO THE WARRANTIES OF MERCHANTABILITY,
 * FITNESS FOR A PARTICULAR PURPOSE AND NONINFRINGEMENT. IN NO EVENT SHALL THE
 * AUTHORS OR COPYRIGHT HOLDERS BE LIABLE FOR ANY CLAIM, DAMAGES OR OTHER
 * LIABILITY, WHETHER IN AN ACTION OF CONTRACT, TORT OR OTHERWISE, ARISING
 * FROM, OUT OF OR IN CONNECTION WITH THE SOFTWARE OR THE USE OR OTHER
 * DEALINGS IN THE SOFTWARE.
 */
/**
 * \file
 * \brief configuration definitions
 */
#ifndef SdFatConfig_h
#define SdFatConfig_h
#include <Arduino.h>
#include <stdint.h>
#ifdef __AVR__
#include <avr/io.h>
#endif  // __AVR__
//------------------------------------------------------------------------------
/**
 * Set INCLUDE_SDIOS nonzero to include sdios.h in SdFat.h.
 * sdios.h provides C++ style IO Streams.
 */
#define INCLUDE_SDIOS 1
//------------------------------------------------------------------------------
/**
 * Set USE_LONG_FILE_NAMES nonzero to use long file names (LFN).
 * Long File Name are limited to a maximum length of 255 characters.
 *
 * This implementation allows 7-bit characters in the range
 * 0X20 to 0X7E except the following characters are not allowed:
 *
 *  < (less than)
 *  > (greater than)
 *  : (colon)
 *  " (double quote)
 *  / (forward slash)
 *  \ (backslash)
 *  | (vertical bar or pipe)
 *  ? (question mark)
 *  * (asterisk)
 *
 */
#define USE_LONG_FILE_NAMES 0
//------------------------------------------------------------------------------
/**
 * If the symbol ENABLE_EXTENDED_TRANSFER_CLASS is nonzero, the class SdFatEX
 * will be defined. If the symbol ENABLE_SOFTWARE_SPI_CLASS is also nonzero,
 * the class SdFatSoftSpiEX will be defined.
 *
 * These classes used extended multi-block SD I/O for better performance.
 * the SPI bus may not be shared with other devices in this mode.
 */
#define ENABLE_EXTENDED_TRANSFER_CLASS 0
//------------------------------------------------------------------------------
/**
 * If the symbol USE_STANDARD_SPI_LIBRARY is zero, an optimized custom SPI
 * driver is used if it exists.  If the symbol USE_STANDARD_SPI_LIBRARY is
 * one, the standard Arduino SPI.h library is used with SPI. If the symbol
 * USE_STANDARD_SPI_LIBRARY is two, the SPI port can be selected with the
 * constructors SdFat(SPIClass* spiPort) and SdFatEX(SPIClass* spiPort).
 */
#define USE_STANDARD_SPI_LIBRARY 0
//------------------------------------------------------------------------------
/**
 * If the symbol ENABLE_SOFTWARE_SPI_CLASS is nonzero, the class SdFatSoftSpi
 * will be defined. If ENABLE_EXTENDED_TRANSFER_CLASS is also nonzero,
 * the class SdFatSoftSpiEX will be defined.
 */
#define ENABLE_SOFTWARE_SPI_CLASS 0
//------------------------------------------------------------------------------
/** If the symbol USE_FCNTL_H is nonzero, open flags for access modes O_RDONLY,
 * O_WRONLY, O_RDWR and the open modifiers O_APPEND, O_CREAT, O_EXCL, O_SYNC
 * will be defined by including the system file fcntl.h.
 */
#if defined(__AVR__)
// AVR fcntl.h does not define open flags.
#define USE_FCNTL_H 0
#elif defined(PLATFORM_ID)
// Particle boards - use fcntl.h.
#define USE_FCNTL_H 1
#elif defined(__arm__)
// ARM gcc defines open flags.
#define USE_FCNTL_H 1
#elif defined(ESP32)
#define USE_FCNTL_H 1
#else  // defined(__AVR__)
#define USE_FCNTL_H 0
#endif  // defined(__AVR__)
//------------------------------------------------------------------------------
/**
 * If CHECK_FLASH_PROGRAMMING is zero, overlap of single sector flash
 * programming and other operations will be allowed for faster write
 * performance.
 *
 * Some cards will not sleep in low power mode unless CHECK_FLASH_PROGRAMMING
 * is non-zero.
 */
#define CHECK_FLASH_PROGRAMMING 1
//------------------------------------------------------------------------------
/**
 * Set MAINTAIN_FREE_CLUSTER_COUNT nonzero to keep the count of free clusters
 * updated.  This will increase the speed of the freeClusterCount() call
 * after the first call.  Extra flash will be required.
 */
#define MAINTAIN_FREE_CLUSTER_COUNT 0
//------------------------------------------------------------------------------
/**
 * To enable SD card CRC checking set USE_SD_CRC nonzero.
 *
 * Set USE_SD_CRC to 1 to use a smaller CRC-CCITT function.  This function
 * is slower for AVR but may be fast for ARM and other processors.
 *
 * Set USE_SD_CRC to 2 to used a larger table driven CRC-CCITT function.  This
 * function is faster for AVR but may be slower for ARM and other processors.
 */
#define USE_SD_CRC 0
//------------------------------------------------------------------------------
/**
 * Handle Watchdog Timer for WiFi modules.
 *
 * Yield will be called before accessing the SPI bus if it has been more
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

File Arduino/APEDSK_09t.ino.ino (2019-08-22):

/* APEDISK99
* 
* This sketch emulates 3 TI99/4a disk drives. It will need:
*
* 	- Arduino Uno
*	- SD shield (RTC optional but potentially super handy)
*	- APEDSK99 shield
*
* The Arduino RAM interface is based on Mario's EEPROM programmer:
* https://github.com/mkeller0815/MEEPROMMER
*
* $Author: Jochen Buur $
* $Date: Aug 2019 $
* $Revision: 0.12k $
*
* This software is freeware and can be modified, re-used or thrown away without any restrictions.
*
* Use this code at your own risk. 
* I'm not responsible for any bad effect or damages caused by this software
*/

//SPI and SD card functions
#include <SPI.h>
#include <SD.h>

//SPI card select pin
#define SPI_CS 10

//74HC595 shift-out definitions
#define DS	A3
#define LATCH	A4
#define CLOCK	A5

#define PORTC_DS	3
#define PORTC_LATCH	4
#define PORTC_CLOCK	5

//define IO lines for RAM databus
//skip 2 as we need it for interrupts
#define D0 1
#define D1 3
#define D2 4
#define D3 5
#define D4 6
#define D5 7
#define D6 8
#define D7 9

//define IO lines for RAM control
#define CE		A0	//LED flashes for both Arduino CE* and TI MBE*
#define WE		A2
#define PORTC_CE   	0
#define PORTC_WE   	2

//define IO lines for TI99/4a control
#define TI_BUFFERS 	A1	//74LS541 buffers enable/disable
#define TI_READY    	0	//TI READY line + enable/disable 74HC595 shift registers
#define TI_INT      	2	//74LS138 interrupt (MBE*, WE* and A15) 

//flag from interrupt routine to signal possible new FD1771 command
volatile byte FD1771 = 0;

//generic variable for r/w DSRAM
byte DSRAM = 0;

//CRU emulation bytes + FD1771 registers
#define CRURD   0x1FEC     //emulated 8 CRU input bits
#define CRUWRI  0x1FEE     //emulated 8 CRU output bits
#define RSTAT   0x1FF0     //read FD1771 Status register
#define RTRACK  0x1FF2     //read FD1771 Track register
#define RSECTR  0x1FF4     //read FD1771 Sector register
#define RDATA   0x1FF6     //read FD1771 Data register
#define WCOMND  0x1FF8     //write FD1771 Command register
#define WTRACK  0x1FFA     //write FD1771 Track register
#define WSECTR  0x1FFC     //write FD1771 Sector register
#define WDATA   0x1FFE     //write FD1771 Data register

//error blinking parameters: on, off, delay between sequence
#define LED_on  350
#define LED_off 250
#define LED_repeat 1500

//input and output file pointers
File InDSR;
File InDSK1;
File OutDSK1;
File InDSK2;
File OutDSK2;
File InDSK3;
File OutDSK3;

//flags for additional "drives" available
boolean DSK2 = LOW;
boolean DSK3 = LOW;

//----- RAM, I/O data and control functions

//switch databus to INPUT state
void dbus_in() {
  pinMode(D0, INPUT);
  pinMode(D1, INPUT);
  pinMode(D2, INPUT);
  pinMode(D3, INPUT);
  pinMode(D4, INPUT);
  pinMode(D5, INPUT);
  pinMode(D6, INPUT);
  pinMode(D7, INPUT);
}

//switch databus to OUTPUT state
void dbus_out() {
  pinMode(D0, OUTPUT);
  pinMode(D1, OUTPUT);
  pinMode(D2, OUTPUT);
  pinMode(D3, OUTPUT);
  pinMode(D4, OUTPUT);
  pinMode(D5, OUTPUT);
  pinMode(D6, OUTPUT);
  pinMode(D7, OUTPUT);
}

//disable Arduino control bus
void dis_cbus() {
  pinMode(CE, INPUT);
  pinMode(WE, INPUT);
}
 
//enable Arduino control bus
void ena_cbus() {
  pinMode(CE, OUTPUT);
  pinMode(WE, OUTPUT);
}

//read a complete byte from the databus
//be sure to set databus to input first!
byte dbus_read()
{
  return ((digitalRead(D7) << 7) +
          (digitalRead(D6) << 6) +
          (digitalRead(D5) << 5) +
          (digitalRead(D4) << 4) +
          (digitalRead(D3) << 3) +
          (digitalRead(D2) << 2) +
          (digitalRead(D1) << 1) +
           digitalRead(D0));
}

//write a byte to the databus
//be sure to set databus to output first!
void dbus_write(byte data)
{
  digitalWrite(D7, (data >> 7) & 0x01);
  digitalWrite(D6, (data >> 6) & 0x01);
  digitalWrite(D5, (data >> 5) & 0x01);
  digitalWrite(D4, (data >> 4) & 0x01);
  digitalWrite(D3, (data >> 3) & 0x01);
  digitalWrite(D2, (data >> 2) & 0x01);
  digitalWrite(D1, (data >> 1) & 0x01);
  digitalWrite(D0, data & 0x01);  
}

//shift out the given address to the 74HC595 registers
void set_abus(unsigned int address)
{
  //get MSB of 16 bit address
  byte MSB = address >> 8;
  //get LSB of 16 bit address
  byte LSB = address & 0xFF;

  //disable latch line
  bitClear(PORTC,PORTC_LATCH);

  //shift out MSB byte
  fastShiftOut(MSB);
  //shift out LSB byte
  fastShiftOut(LSB);

  //enable latch and set address
  bitSet(PORTC,PORTC_LATCH);
}

//faster shiftOut function then normal IDE function (about 4 times)
void fastShiftOut(byte data) {
  //clear data pin
  bitClear(PORTC,PORTC_DS);
  //send each bit of the data byte; MSB first
  for (int i=7; i>=0; i--)  {
    bitClear(PORTC,PORTC_CLOCK);
    //Turn data on or off based on value of bit
    if ( bitRead(data,i) == 1 ) {
      bitSet(PORTC,PORTC_DS);
    }
    else {      
      bitClear(PORTC,PORTC_DS);
    }
    //register shifts bits on upstroke of clock pin  
    bitSet(PORTC,PORTC_CLOCK);
    //zero the data pin after shift to prevent bleed through
    bitClear(PORTC,PORTC_DS);
  }
  //stop shifting
  bitClear(PORTC,PORTC_CLOCK);
}

//short function to set RAM CE* (OE* and CS) are permanenty enabled)
void set_CE (byte state)
{
  digitalWrite(CE, state);
}

//short function to set RAM WE* (Write Enable)
void set_WE (byte state)
{
  digitalWrite(WE, state);
}

//short function to enable/disable TI interface 74LS541 buffers
void TIbuf (byte state)
{
  digitalWrite(TI_BUFFERS, state);
}

//short function to set TI READY line (pause/resume TI); 74HC595 buffers are !set at the same time
void TIready (byte state)
{
  digitalWrite(TI_READY, state);
}
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

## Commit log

2019-07-26 initial upload
    [APEDSK-AU-Edge_Cuts.gbr, APEDSK-AU-F_Mask.gbr, APEDSK-AU-F_SilkS.gbr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]
2019-07-28 KiCAD 3D view
2019-08-18 Latest files
    Latest files
    [APEDSK-AU-B_CrtYd.gbr, APEDSK-AU-B_Fab.gbr, APEDSK-AU-B_Mask.gbr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]
2019-08-19 Create APEDSK_09t.ino.ino
    Arduino initial upload
2019-08-21 Update Arduino code
    various optimisations and prep for testing
2019-09-18 R1, MBE
    [APEDSK-AU.kicad_pcb, APEDSK-AU.sch]
2019-12-15 Create APEDSK99-a99 labels.xlsx
    [APEDSK99-a99 labels.xlsx]
2019-12-31 Revert "Update APEDSK_09t.ino"
    This reverts commit 656828adfe1e1bea3e13d7ffca015ee6a3765fd3.
    [APEDSK_09t.ino]
2019-12-31 Revert "Update APEDSK_09t.ino"
    This reverts commit 96daebb74852cc13297dd614e1c9990a80ab753d.
    [APEDSK_09t.ino]
2019-12-31 Revert "Update APEDSK_09t.ino"
    This reverts commit c9fa2d989d53acfff8560bc7cf14c6a875eeffd5.
    [APEDSK_09t.ino]
2019-12-31 Revert "Update APEDSK_09t.ino"
    This reverts commit 306ef4f904288ca78033c3bca7c58074774c5492.
    [APEDSK_09t.ino]
2020-02-01 update
    update
    [APEDSK-AU.kicad_pcb, APEDSK-AU.sch]
2020-02-24 Revert "UPDATE"
    This reverts commit 5350772d7cc5dfb49a72b10eaf452a5211ef6d4f.
    [APEDSK_09t.ino]
2020-03-17 update R4 value
    R4 value
    [APEDSK-AU.sch]
2020-03-19 timiing
    wrestling with interrupts
2020-05-28 A15 to 74LS138/E3
    In preparation for Ethernet connectivity 74LS138 E3 (part of interrupt generation) is now directly connected to TI A15 instead of AD_D0. No interrupt pulse present anymore on TI_INT during Arduino pr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
2020-08-21 Added R5 for D2:TI_INT/ETH_CS shared use
    [APEDSK-AU.kicad_pcb, APEDSK-AU.sch]
2020-08-26 1K protection resistor TI_INT/ETH_CC; R6 ipv R4 for jump table index
2020-08-28 LDSK() switch DSK during ">" fix
2020-09-06 added R6 noise supression resistor
    [APEDSK-AU.kicad_pcb, APEDSK-AU.sch]
2021-02-04 APEETH99 -> APEDSK99
    [APEDSK-AU-B_CrtYd.gbr, APEDSK-AU-B_Fab.gbr, APEDSK-AU-B_Mask.gbr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]
2021-04-26 Silkscreen update
    [APEDSK-AU.kicad_pcb]
2022-01-03 TIME
    removed automatic date / time printing from TIME command
2022-01-03 Update APEDSK99.a99
    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
2022-06-21 KiCad V6 / D2
    Migrated project to KiCad v6
    Replaced R6 with D2 to remove video interference
    [APEDSK-AU.kicad_pcb, APEDSK-AU.kicad_sch]
2022-06-21 version 12.p
    Sync version with KiCad project
2022-06-29 Gerber + drill file
    Gerber + drill file for JCLPCB
    [APEDSK-AU-B_Courtyard.gbr, APEDSK-AU-B_Fab.gbr, APEDSK-AU-B_Mask.gbr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]
2022-11-30 12p->12q reduced memory footprint
2022-12-01 MDSK/RDSK/FGET/FPUT error
    These commands would generate an error if they were the first executed after a reset. (effectively DSK0--)
    [APEDSK99_012q-H-AD99cmd.ino]
2022-12-03 Reduced memory footprint
2022-12-18 NDSK
    New rename DSK command. Better error checking on CALL's in DSR
    [APEDSK99_012r-D-dsr_msg_ntp.ino, APEDSK99_012r-H-AD99cmd.ino]
2022-12-20 error check, added NDIR
    [APEDSK99_012r-D-dsr_msg_ntp.ino, APEDSK99_012r-H-AD99cmd.ino]
2022-12-26 string argument process error fixed
    [APEDSK99_012r-H-AD99cmd.ino]
2022-12-30 improved AHLP, SDSK d/t bug
    [APEDSK99_012r-D-dsr_msg_ntp.ino, APEDSK99_012r-H-AD99cmd.ino]
2022-12-31 NTP error handling bug
    [APEDSK99_012r-D-dsr_msg_ntp.ino, APEDSK99_012r-H-AD99cmd.ino]
2023-01-13 NDIR / MDSK bug
    [APEDSK99_012r-H-AD99cmd.ino]
2023-01-23 ARST version print; subcommand structure
2023-02-21 help and error external
    [APEDSK99_012r-D-dsr_msg_ntp.ino, APEDSK99_012r-H-AD99cmd.ino]
2023-03-09 string functions, module support
    - replaced memory-hungry strnxxx functions and sprintf() with homegrown versions
    - CALL LINK support added for E/A and MM
    [APEDSK99_012r.ino, APEDSK99_012s-B-HAL.ino, APEDSK99_012s-C-global_suppfnc.ino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]
2023-03-12 8 character DSK bug / FAT sorter
    [APEDSK99_012s-C-global_suppfnc.ino, APEDSK99_012s-G-AD99cmd.ino]
2023-03-14 further reduction memory footprint
    quite a journey
2023-03-25 further footprint reduction
2023-04-13 documentation errors
    [APEDSK-AU-BOM.xlsx]
2024-01-17 schematic cleanup
    [APEDSK-AU.kicad_pcb, APEDSK-AU.kicad_sch, APEDSK-AU.sch]
2024-01-20 build instructions, case files
    [APEDSK99 Bottom.stl, APEDSK99 Lid.stl, APEDSK99 Top.stl]
2024-01-23 KiCad FS error + updated BOM
    [APEDSK-AU-BOM.xlsx]
2024-03-22 updated case 3D files
    [APEDSK99 Bottom 2024 Fix.stl, APEDSK99 Bottom.stl, APEDSK99 Top 2024 Fix.stl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]

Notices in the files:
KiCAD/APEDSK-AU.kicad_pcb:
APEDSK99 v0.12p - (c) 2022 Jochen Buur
